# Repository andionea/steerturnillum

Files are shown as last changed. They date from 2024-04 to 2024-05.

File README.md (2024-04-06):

# SteerTurnIllum

## Getting started

To make it easy for you to get started with GitLab, here's a list of recommended next steps.

Already a pro? Just edit this README.md and make it your own. Want to make it easy? [Use the template at the bottom](#editing-this-readme)!

## Add your files

- [ ] [Create](https://docs.gitlab.com/ee/user/project/repository/web_editor.html#create-a-file) or [upload](https://docs.gitlab.com/ee/user/project/repository/web_editor.html#upload-a-file) files
- [ ] [Add files using the command line](https://docs.gitlab.com/ee/gitlab-basics/add-file.html#add-a-file-using-the-command-line) or push an existing Git repository with the following command:

```
cd existing_repo
git remote add origin https://gitlab.com/teodora.cristea/steerturnillum-ttc2.git
git branch -M main
git push -uf origin main
```

## Integrate with your tools

- [ ] [Set up project integrations](https://gitlab.com/teodora.cristea/steerturnillum-ttc2/-/settings/integrations)

## Collaborate with your team

- [ ] [Invite team members and collaborators](https://docs.gitlab.com/ee/user/project/members/)
- [ ] [Create a new merge request](https://docs.gitlab.com/ee/user/project/merge_requests/creating_merge_requests.html)
- [ ] [Automatically close issues from merge requests](https://docs.gitlab.com/ee/user/project/issues/managing_issues.html#closing-issues-automatically)
- [ ] [Enable merge request approvals](https://docs.gitlab.com/ee/user/project/merge_requests/approvals/)
- [ ] [Set auto-merge](https://docs.gitlab.com/ee/user/project/merge_requests/merge_when_pipeline_succeeds.html)

## Test and Deploy

Use the built-in continuous integration in GitLab.

- [ ] [Get started with GitLab CI/CD](https://docs.gitlab.com/ee/ci/quick_start/index.html)
- [ ] [Analyze your code for known vulnerabilities with Static Application Security Testing (SAST)](https://docs.gitlab.com/ee/user/application_security/sast/)
- [ ] [Deploy to Kubernetes, Amazon EC2, or Amazon ECS using Auto Deploy](https://docs.gitlab.com/ee/topics/autodevops/requirements.html)
- [ ] [Use pull-based deployments for improved Kubernetes management](https://docs.gitlab.com/ee/user/clusters/agent/)
- [ ] [Set up protected environments](https://docs.gitlab.com/ee/ci/environments/protected_environments.html)

***

# Editing this README

When you're ready to make this README your own, just edit this file and use the handy template below (or feel free to structure it however you want - this is just a starting point!). Thanks to [makeareadme.com](https://www.makeareadme.com/) for this template.

## Suggestions for a good README

Every project is different, so consider which of these sections apply to yours. The sections used in the template are suggestions for most open source projects. Also keep in mind that while a README can be too long and detailed, too long is better than too short. If you think your README is too long, consider utilizing another form of documentation rather than cutting out information.

## Name
Choose a self-explaining name for your project.

## Description
Let people know what your project can do specifically. Provide context and add a link to any reference visitors might be unfamiliar with. A list of Features or a Background subsection can also be added here. If there are alternatives to your project, this is a good place to list differentiating factors.

## Badges
On some READMEs, you may see small images that convey metadata, such as whether or not all the tests are passing for the project. You can use Shields to add some to your README. Many services also have instructions for adding a badge.

## Visuals
Depending on what you are making, it can be a good idea to include screenshots or even a video (you'll frequently see GIFs rather than actual videos). Tools like ttygif can help, but check out Asciinema for a more sophisticated method.

## Installation
Within a particular ecosystem, there may be a common way of installing things, such as using Yarn, NuGet, or Homebrew. However, consider the possibility that whoever is reading your README is a novice and would like more guidance. Listing specific steps helps remove ambiguity and gets people to using your project as quickly as possible. If it only runs in a specific context like a particular programming language version or operating system or has dependencies that have to be installed manually, also add a Requirements subsection.

## Usage
Use examples liberally, and show the expected output if you can. It's helpful to have inline the smallest example of usage that you can demonstrate, while providing links to more sophisticated examples if they are too long to reasonably include in the README.

## Support
Tell people where they can go to for help. It can be any combination of an issue tracker, a chat room, an email address, etc.

## Roadmap
If you have ideas for releases in the future, it is a good idea to list them in the README.

## Contributing
State if you are open to contributions and what your requirements are for accepting them.

For people who want to make changes to your project, it's helpful to have some documentation on how to get started. Perhaps there is a script that they should run or some environment variables that they need to set. Make these steps explicit. These instructions could also be useful to your future self.

You can also document commands to lint the code or run tests. These steps help to ensure high code quality and reduce the likelihood that the changes inadvertently break something. Having instructions for running tests is especially helpful if it requires external setup, such as starting a Selenium server for testing in a browser.

## Authors and acknowledgment
Show your appreciation to those who have contributed to the project.

## License
For open source projects, say how it is licensed.

## Project status
If you have run out of energy or time for your project, put a note at the top of the README saying that development has slowed down or stopped completely. Someone may choose to fork your project or volunteer to step in as a maintainer or owner, allowing your project to keep going. You can also make an explicit request for maintainers.

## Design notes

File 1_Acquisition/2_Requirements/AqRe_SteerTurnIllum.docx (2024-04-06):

System Requirements

SteerTurnIllum

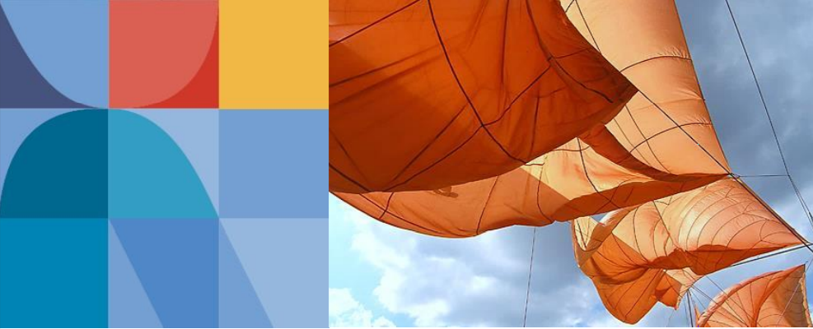
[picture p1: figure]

Author: | | Nicolae-Bogdan Bacrău
Version: | | 1.0

# Index

# 1 Glossary

This section contains a glossary of all the important terms and acronyms used inside the document.

Term / Acronym | Description
ECU | Electronic Control Unit
uC | Microcontroller
ADC | Analog Digital Converter
PWM | Pulse Width Modulation
EMC | Electromagnetic Compatibility

Table 1 - Glossary.

# 2 Introduction

## Purpose of the Document

The purpose of the document is to define the system requirements of the SteerTurnIllum embedded academy project.

## Overview

SteerTurnIllum is an abbreviation of Steering, Turning and Illumination, which represent the functional features of the emulated vehicle system:

1) Steering:
- Steering control of the vehicle through movements of a joystick, emulating the wheel, and indicated by servomotor angles.
- Horn control of the vehicle through pressing of a dedicated horn button and indicated by a buzzer activation.
2) Turning: control of turn signals (left, right and hazard signaling) through pressing three turn indication buttons and indicated on four turn indication LEDs through blinking; the position of the wheel can also stop the left or right turn indications.
3) Illumination: control of the vehicle board illumination through a potentiometer emulating the outer luminance and indicated on two illumination fading LEDs.

The system presents one extra feature, named Vehicle Management, which enables the user to switch between a normal state, in which the three functional states are active, and a configuration state in which several runtime configuration parameters can be set up which affect the behavior of the steering, turning and illumination features.

# 3 Methodology

## Steering

In the cars, the most conventional steering arrangement is to turn the front wheels using a hand operated steering wheel. Depending on the geometry of the wheels while steering, there are two possible steering control types:

- Parallel steering geometry: the wheels turn an identical angle when steering.
- Ackermann steering geometry: the inside wheel turns a greater angle than the outside wheel to follow the smaller radius that the inside wheel takes on a turn.

The two steering geometries are presented in Figure 1.

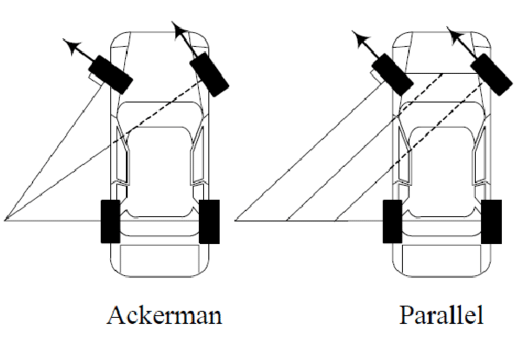
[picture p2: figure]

Figure 1 - Parallel vs Ackermann steering geometries.

While the parallel steering geometry is straightforward (the angles of the two wheels are identical), the Ackermann steering geometry defines a mathematical formula between the two angles, named: inner angle, δi (left angle when turning left, right angle when turning right) and the outer angle, δo (right angle when turning left, left angle when turning right). The Ackermann steering geometry is presented in Figure 2.

The Ackermann steering mathematical equation is:

ctg(δ_o )- ctg(δ_i )= w/l

Let w be half the size of l. In this case the equation of δo depending on δi is:

δ_o =arcctg(1/2+ctg(δ_i ))

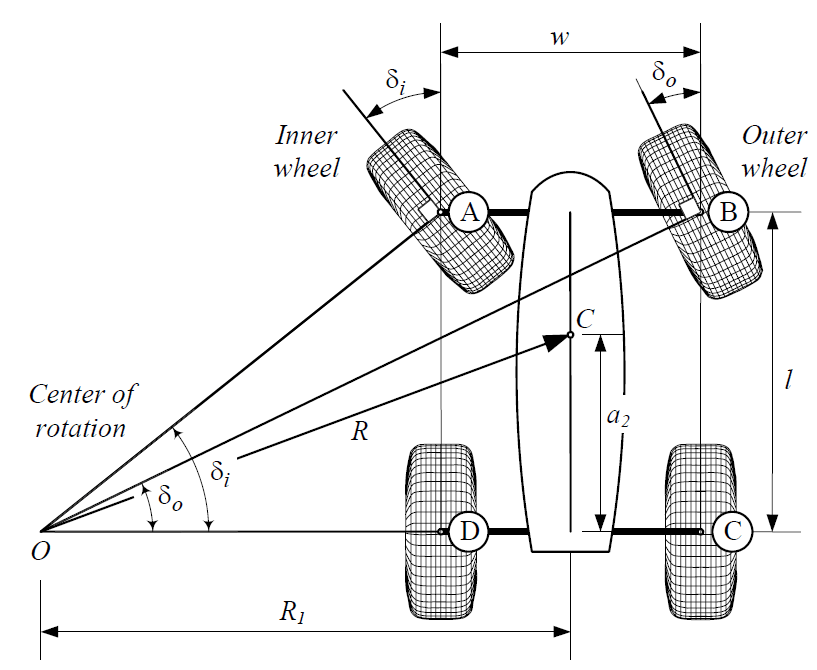
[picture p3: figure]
A-front-wheel-steering-vehicle-and-steer-angles-of-the-inner-and-outer-wheels

Figure 2 - Ackermann steering geometry.

A plot of outer wheel angles depending on inner wheel values is presented in Figure 3.

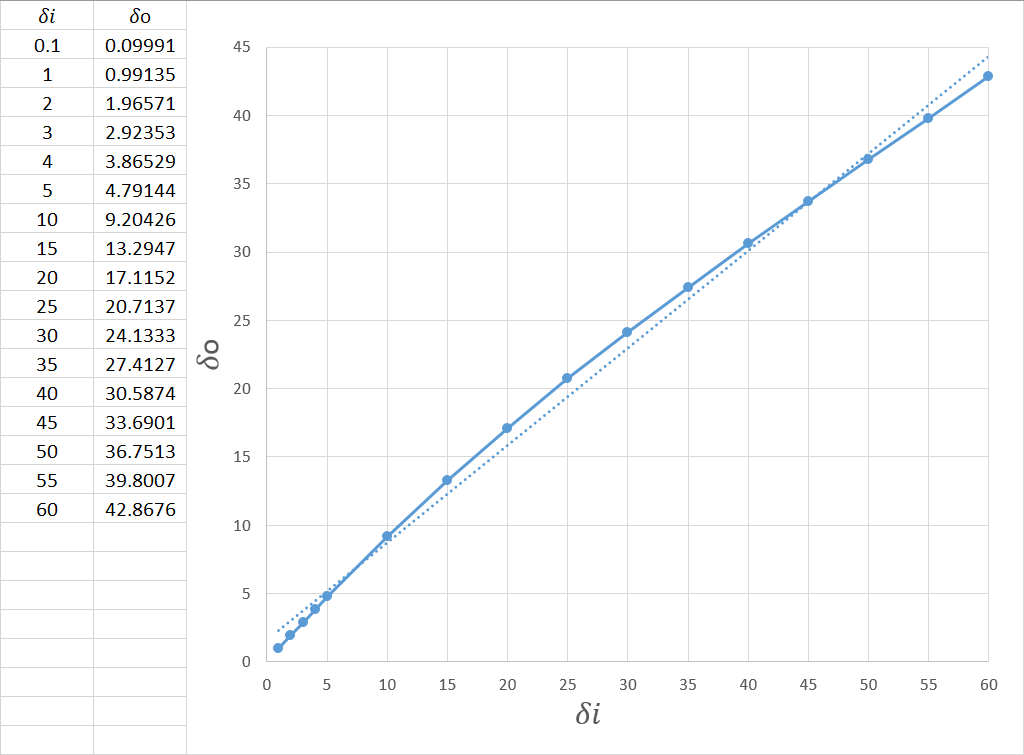
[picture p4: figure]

Figure 3 - Ackermann outer angles depending on inner angles.

The equation can be approximated through 4 linear equations, as shown in Figure 4.

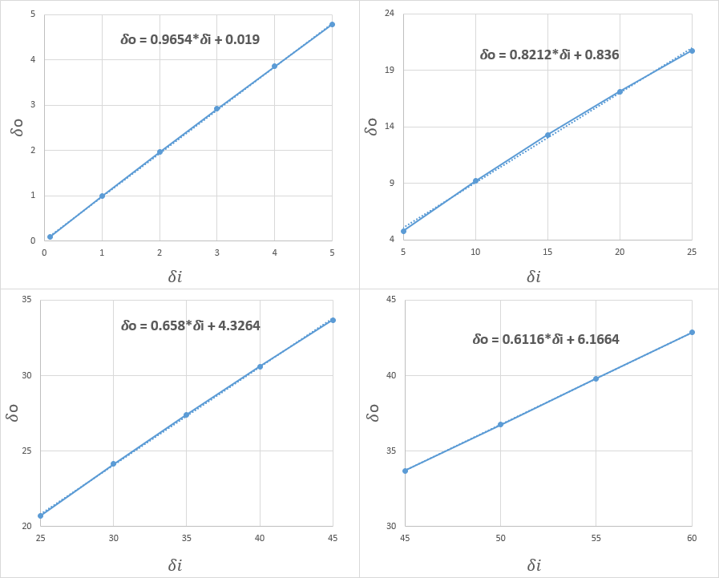
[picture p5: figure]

Figure 4 - Ackermann linear functions in the (0..60] degrees interval.

The 4 linear equations can be applied for inner angles in the (0..60] degrees interval. The Ackermann equation does not make sense for an inner angle of 0 degrees (ctg(0) is undefined). Therefore, when the inner angle is 0 the outer angle is also 0.

For more details see ./Resources/AqRe_Graphs.xlsx → Ackermann.

## Debouncing

In order to avoid frequent switching of the output values because of mechanical contact oscillation at button presses and releases, or because of EMC influence, the input values are debounced. This consists of considering a larger time interval than the contact maximum oscillation period or the EMC influence period in which the input values must be stable. By doing so, the probability of considering a wrong button state is greatly reduced.

Debouncing is defined by two values: the debounce window, representing the time period in which an input must be stable, and the debounce depth defining the number of times an input is sampled in the debounce window.

An example showing the result of a debounce with a depth of 4 on a button input signal that is affected by noise is illustrated in Figure 5.

Figure 5 - Debounce of a button input affected by noise.

A debounce depth of N means a debounce window equal to the sum of N-1 acquisition time window periodicities. In the given example, if the acquisition time would be 5 ms, then the debounce depth of 4 would mean a debounce window of (4-1)*5 = 15 ms.

Each mechanical button component has a maximum bouncing period of the contacts that is defined by the manufacturer / supplier of the component. It must be ensured that the chosen debounce time is larger than the defined bouncing period.

A measure for reducing the probability of erroneous button press events is to increase the debounce time of the buttons.

Observation: the debounce time greatly affects the response time, therefore it should be kept as low as possible (usually below 20 ms).

## Moving Average

A moving average is a simple Low Pass FIR (Finite Impulse Response) filter commonly used for regulating an array of sampled data. It takes a number of samples of input at a time, defining the Depth, and calculates the average of those samples, producing a single output value. As the length of the filter increases, the smoothness of the output increases, whereas the sharp modulations in the data are made increasingly blunt.

A moving average filter is described by the following formula:

F(t_x )=(∑_(k=x-D+1)^x S(t_x ))/D

- tx – a given point in time (timestamp);
- D – the filter depth;
- S(tx) – the sampled input signal;
- F(tx) – the filtered output.

An example of an input signal (S(tx)) and the output of a moving average filter (F(tx)) with a depth of 3 (D = 3) is presented in Figure 6.

Figure 6 - Moving average example.

For the given example, the filtered output in t5 is:

F(t_5 )=(S(t_3 )+S(t_4 )+S(t_5 ))/3=(2+8+5)/3=5

An example of filtering the output of a noisy ADC with a depth of 5 is presented in Figure 7.

Figure 7 - Moving average on a noisy ADC output.

The filtering operation adds a delay between the input values and the output values. For example, applying a moving average with D = 10 over the (0, 10, 10, 10, 10, 10, 10, 10, 10, 10, 10) input, results in the (0, 1, 2, 3, 4, 5, 6, 7, 8, 9, 10) output.

Observation: the depth of the moving average greatly affects the response time, therefore it should be kept as low as possible.

For more details see ./Resources/AqRe_Graphs.xlsx → Moving average.

## Fading

Sudden changes in the illumination levels are very easily observable by the human eye and can distract the driver’s attention. In order to diminish this effect, a slow transition between two illumination levels is needed. The transition, also called fading, consists of a series of intermediate illumination levels over a long period of time.

The illumination level is usually controlled via PWM signals applied on illumination LEDs. The actual illumination levels of the LEDs are not linearly correlated to the PWM duty cycle percentages, the changes in the illumination levels being more sensitive when the duty cycles are low. Therefore, in order to obtain a more linear transition of illumination levels, the used PWM duty cycles shall follow a non-linear equation. A good non-linear equation that satisfies a linear transition of illumination levels is:

FadingLevel(x)=x^4 , x∈[0, 1]

FadingLevel(x) takes values in the [0, 1] interval, defining PWM duty cycle percentages in the [0, 100]% interval. The graph of FadingLevel(x), using PWM duty cycle percentages, is presented in Figure 8.

Figure 8 - Fading levels graph.

Two examples of PWM duty cycle fading using the given equation are presented in Figure 9 and Figure 10.

Figure 9 - Fading PWM duty cycles from 0% to 30% in 150 ms with an update rate of 10 ms.

Figure 10 - Fading PWM duty cycles from 100% to 50% in 100 ms with an update rate of 10 ms.

For more details see ./Resources/AqRe_Graphs.xlsx → Fading.

# 4 System Requirements

## General

[SYRE_GEN_1] The system shall contain 3 x buttons for controlling the turn signals and 1 x button for controlling the horn activation, named and arranged in the following left to right order: BTN_LEFT, BTN_RIGHT, BTN_HAZARD, BTN_HORN.
[SYRE_GEN_2] The system shall contain 1 x joystick for controlling the steering angle, named JOY_STEER.
[SYRE_GEN_3] The JOY_STEER joystick shall be positioned such that left-right movements shall influence the steering control, left-most position meaning the 0% position and the right-most position meaning the 100% position. Top-bottom movements shall have no effect on the steering control. By default, the stick shall sit in the 50% position.
[SYRE_GEN_4] The system shall contain 1 x potentiometer for controlling the luminance, named POT_LUMINANCE.
[SYRE_GEN_5] The system shall contain 1 x buzzer for indicating the activation of the horn: BUZZ_HORN.
[SYRE_GEN_6] The system shall contain 4 x LEDs for indicating the turn signals, arranged in a square shape and named in the following clockwise order, starting from top-left: LED_TURN_FRONT_LEFT, LED_TURN_FRONT_RIGHT, LED_TURN_BACK_RIGHT, LED_TURN_BACK_LEFT.
[SYRE_GEN_7] The system shall contain 2 x red LEDs for indicating the board illumination, named and arranged in the following left to right order: LED_ILLUM_NIGHT, LED_ILLUM_DAY.
[SYRE_GEN_8] LED_ILLUM_NIGHT and LED_ILLUM_DAY shall be controlled via PWM channels with a frequency of 1600 Hz +- 10% and a duty cycle resolution of 0.01%.
[SYRE_GEN_9] The system shall contain 1 x dual 7 segments display for indicating the configuration states, named DISP7SEG.
[SYRE_GEN_10] The system shall contain 2 x servomotors for indicating the steering of the wheels, named and arranged in the following left to right order: SERVO_TURN_LEFT, SERVO_TURN_RIGHT.
[SYRE_GEN_11] All buttons shall be debounced in a 10 ms debounce window with a minimum depth of 3 (for more details see Chapter 3.2).
[SYRE_GEN_12] All analog channels shall be filtered using a moving average with a depth size of 5 over a 10 ms period (for more details see Chapter 3.3).

## Vehicle Management

[SYSRE_VEHM_1] The system shall implement the state machine illustrated in Figure 11.

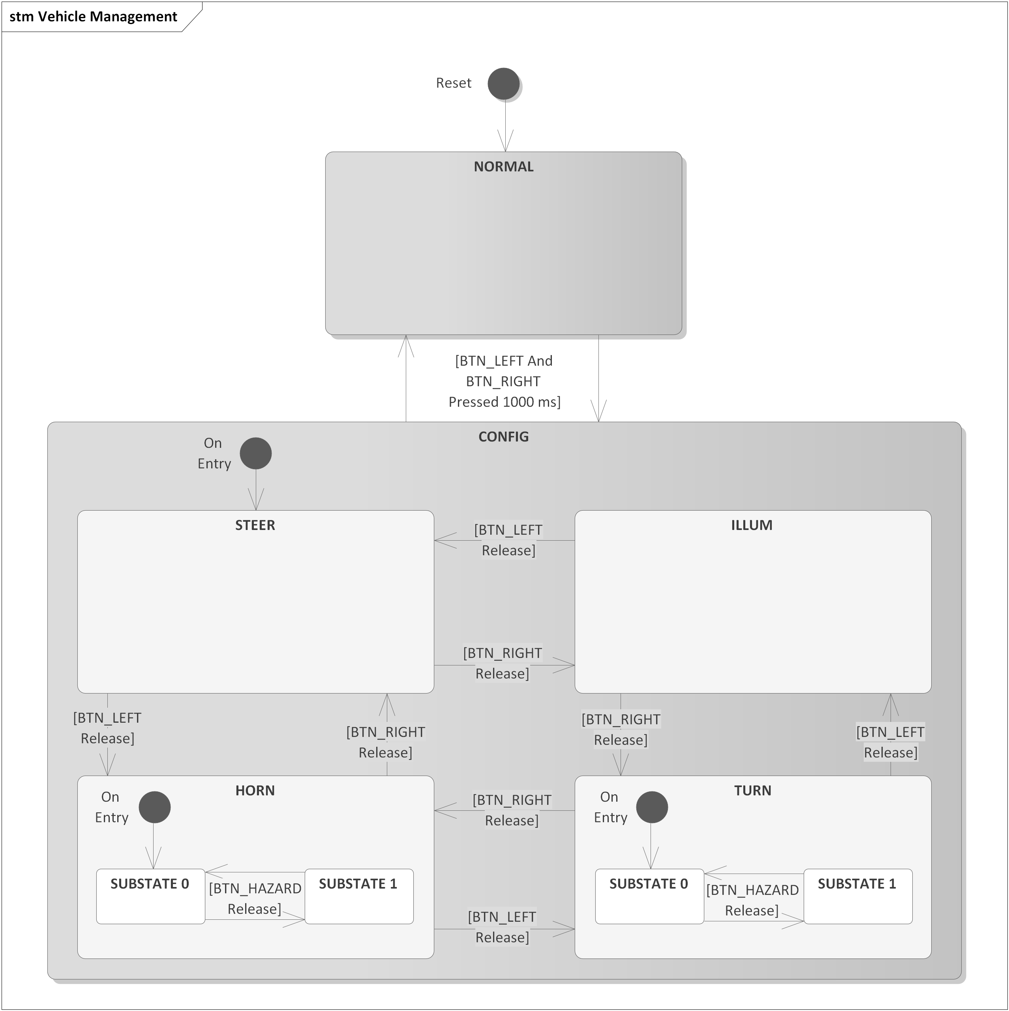
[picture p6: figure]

Figure 11 - Vehicle states and substates.

[SYSRE_VEHM_2] The default vehicle state after a reset shall be NORMAL.
[SYSRE_VEHM_3] The system shall set and react to the following runtime configuration parameters:
- SteerConfig: specifies the wheel steering outer angle calculation method – STEER_CONFIG_PARALLEL (0) or STEER_CONFIG_ACKERMANN (1).
- IllumConfig: specifies the period of the illumination fading – [300, 1000] ms – with a resolution of 10 ms.
- HornConfig:
  - Mode: specifies the horn activation mode – HORN_MODE_CONTINUOUS (0) or HORN_MODE_BEEPING (1).
  - Period: specifies the period of the horn signal while in the HORN_MODE_BEEPING mode – [50, 150] ms – with a resolution of 10 ms.
- TurnConfig:
  - Period: specifies the period of the indication signals – [200, 800] ms – with a resolution of 10 ms.
  - NrOfPeriods: specifies the number of periods to be used on a short turn indication – [2, 5] – with a resolution of 1.
[SYSRE_VEHM_4] The default values for the runtime configuration parameters after a reset shall be:
- SteerConfig = STEER_CONFIG_PARALLEL.
- IllumConfig = 500 ms.
- HornConfig.Mode = HORN_MODE_CONTINUOUS.
- HornConfig.Period = 100 ms.
- TurnConfig.Period = 500 ms.
- TurnConfig.NrOfPeriods = 3.
[SYSRE_VEHM_5] While in the CONFIG vehicle state, BUZZ_HORN shall be continuously inactive.
[SYSRE_VEHM_6] While in the CONFIG vehicle state SERVO_TURN_LEFT and SERVO_TURN_RIGHT shall be set in opposing directions at an inner angle of 45 degrees (135 degrees for SERVO_TURN_LEFT and 45 degrees for SERVO_TURN_RIGHT in trigonometric sense).
[SYSRE_VEHM_7] While in the CONFIG vehicle state JOY_STEER shall have no effect.
[SYSRE_VEHM_8] While in the CONFIG vehicle state, the correlation to be implemented between the states, substates, runtime configuration parameters to be saved, LEDs to be turned ON and values to be displayed on DISP7SEG is illustrated in Table 2.

State | Substate | Configuration Parameter | Active LEDs | DISP7SEG Values
STEER | - | SteerConfig | LED_TURN_FRONT_LEFT | [0, 1]
ILLUM | - | IllumConfig | LED_TURN_FRONT_RIGHT | [30, 100], 100 displayed as “1 ”
HORN | SUBSTATE 0 | HornConfig. Mode | LED_TURN_BACK_RIGHT, LED_ILLUM_NIGHT (10%) | [0, 1]
HORN | SUBSTATE 1 | HornConfig. Period | LED_TURN_BACK_RIGHT, LED_ILLUM_DAY (10%) | [5, 15]
TURN | SUBSTATE 0 | TurnConfig. Period | LED_TURN_BACK_LEFT, LED_ILLUM_NIGHT (10%) | [20, 80]
TURN | SUBSTATE 1 | TurnConfig. NrOfPeriods | LED_TURN_BACK_LEFT, LED_ILLUM_DAY (10%) | [2, 5]

Table 2 - Correlation between states, substates, configuration parameters, active LEDs and DISP7SEG values.

[SYSRE_VEHM_9] While in the CONFIG vehicle state and when BTN_HORN is not pressed, the user shall select the value to be set for the current runtime configuration parameter, indicated on DISP7SEG, through POT_LUMINANCE. DISP7SEG dot symbols shall be OFF.
[SYSRE_VEHM_10] While in the CONFIG vehicle state and when BTN_HORN is pressed, the selected value shall be frozen and saved into the current runtime configuration parameter (additional changed via POT_LUMINANCE shall have no effect on the displayed or saved value). DISP7SEG dot symbols shall be ON.

## Steering

[SYRE_STEER_1] The Steering feature shall be active only while in the NORMAL vehicle state.
[SYRE_STEER_2] When entering the NORMAL state, the servomotors shall point forwards and the buzzer shall be muted.
[SYRE_STEER_3] JOY_STEER position shall control the inner angle as follows:
- Left turn: (50 ... 0] % – (0 ... 60] degrees.
- Right turn: (50 ... 100] % – (0 ... 60] degrees.
[SYRE_STEER_4] When SteerConfig = STEER_CONFIG_PARALLEL, the outer angle shall be equal to the inner angle.
[SYRE_STEER_5] When SteerConfig = STEER_CONFIG_ACKERMANN, the outer angle shall be calculated based on the inner angle through the following equations (for more details see Chapter 3.1):
- δo = δi, when δi = 0;
- δo = 0.9654*δi + 0.019, when δi ∈ (0, 5];
- δo = 0.8212* δi + 0.836, when δi ∈ (5, 25];
- δo = 0.658*δi + 4.3264, when δi ∈ (25, 45];
- δo = 0.6116*δi + 6.1664, when δi ∈ (45, 60];
[SYRE_STEER_6] When BTN_HORN is pressed, the buzzer shall be activated as follows:
- When HornConfig.Mode = HORN_MODE_CONTINUOUS, the buzzer shall be continuously active.
- When HornConfig.Mode = HORN_MODE_BEEPING, the buzzer shall be controlled as illustrated in Figure 12.

Figure 12 - Horn beeping control signal.

[SYRE_STEER_7] When BTN_HORN is not pressed, the buzzer shall be continuously inactive.

## Turning

[SYRE_TURN_1] The Turning feature shall be active only while in the NORMAL vehicle state.
[SYRE_TURN_2] The Turning feature shall implement the state machine from Figure 13.

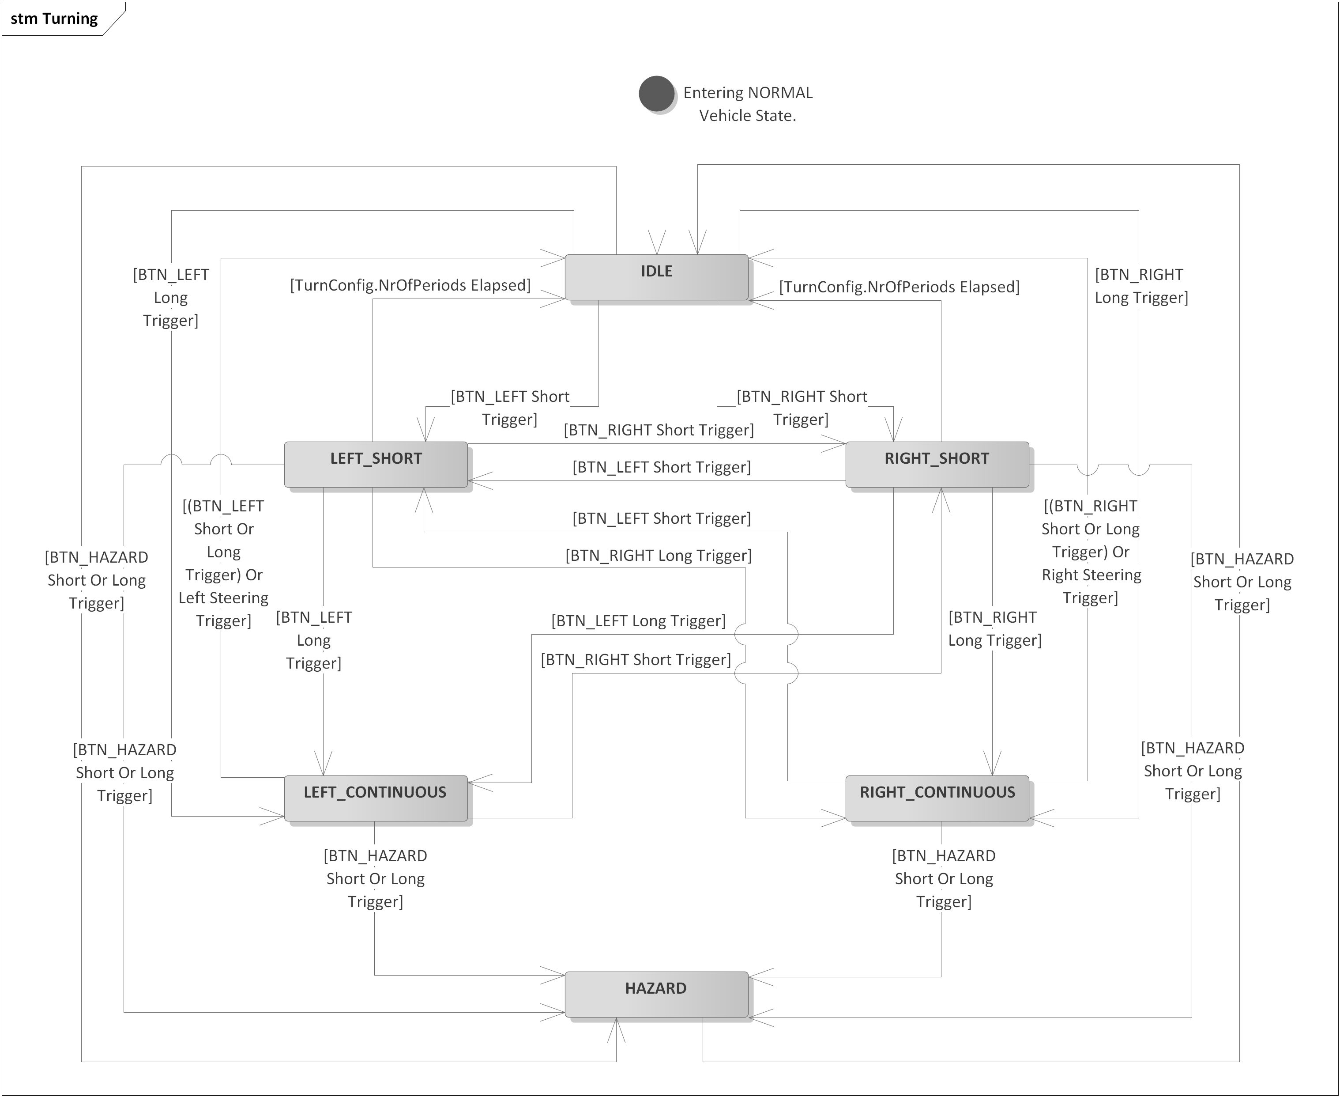
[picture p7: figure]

Figure 13 - Turning state machine.

[SYRE_TURN_3] While in the LEFT_SHORT, RIGHT_SHORT, LEFT_CONTINUOUS, RIGHT_CONTINUOUS, HAZARD states, the blinking LEDs shall be controlled as illustrated in Figure 14.

Figure 14 - LED blinking control signal.

[SYRE_TURN_4] While in the IDLE state, LED_TURN_FRONT_LEFT, LED_TURN_FRONT_RIGHT, LED_TURN_BACK_LEFT and LED_TURN_BACK_RIGHT, shall be turned OFF.
[SYRE_TURN_5] While in the LEFT_SHORT state, LED_TURN_FRONT_LEFT and LED_TURN_BACK_LEFT shall blink a number of times equal to TurnConfig.NrOfPeriods.
[SYRE_TURN_6] While in the RIGHT_SHORT state, LED_TURN_FRONT_RIGHT and LED_TURN_BACK_RIGHT shall blink a number of times equal to TurnConfig.NrOfPeriods.
[SYRE_TURN_7] While in the LEFT_CONTINUOUS state, LED_TURN_FRONT_LEFT and LED_TURN_BACK_LEFT shall blink continuously.
[SYRE_TURN_8] While in the RIGHT_CONTINUOUS state, LED_TURN_FRONT_RIGHT and LED_TURN_BACK_RIGHT shall blink continuously.
[SYRE_TURN_9] While in the HAZARD state, LED_TURN_FRONT_LEFT, LED_TURN_FRONT_RIGHT, LED_TURN_BACK_LEFT and LED_TURN_BACK_RIGHT shall blink continuously.
[SYRE_TURN_10] The short button trigger shall take place on the edge of a button being released after being continuously pressed for a period less than 500 ms.
[SYRE_TURN_11] The long button trigger shall take place when a button has been continuously pressed for a period of 500 ms (keeping the button pressed for more than 500 ms or releasing the button shall not create any other triggers).
[SYRE_TURN_12] The left steering trigger shall take place only in the LEFT_CONTINUOUS state when the steering wheel has reached a position >= 45% after previously reaching a position <= 35%.
[SYRE_TURN_13] The right steering trigger shall take place only in the RIGHT_CONTINUOUS state when the steering wheel has reached a position <= 55% after previously reaching a position >= 65%.

## Illumination

[SYRE_ILLUM_1] The Illumination feature shall be active only while in the NORMAL state.
[SYRE_ILLUM_2] When entering the NORMAL vehicle state, the illumination LEDs shall be OFF.
[SYRE_ILLUM_3] The illumination feature shall implement the state machine illustrated in Figure 15. The Illumination state machine depends on the following values and operations:
- CurrentLuminance: the current value of POT_LUMINANCE.
- AverageLuminance: the average value of CurrentLuminance.
- LastLuminance: the last processed AverageLuminance value for which a fading operation has been triggered.
- Duty(LuminanceValue): the target LED PWM duty cycle corresponding to the given LuminanceValue.
- Fading(LedChannel, StartDuty, TargetDuty, TimeMs): fading operation for the LedChannel LED, starting from the StartDuty PWM duty cycle, finishing when the TargetDuty PWM duty cycle value is reached, over a period of TimeMs miliseconds.

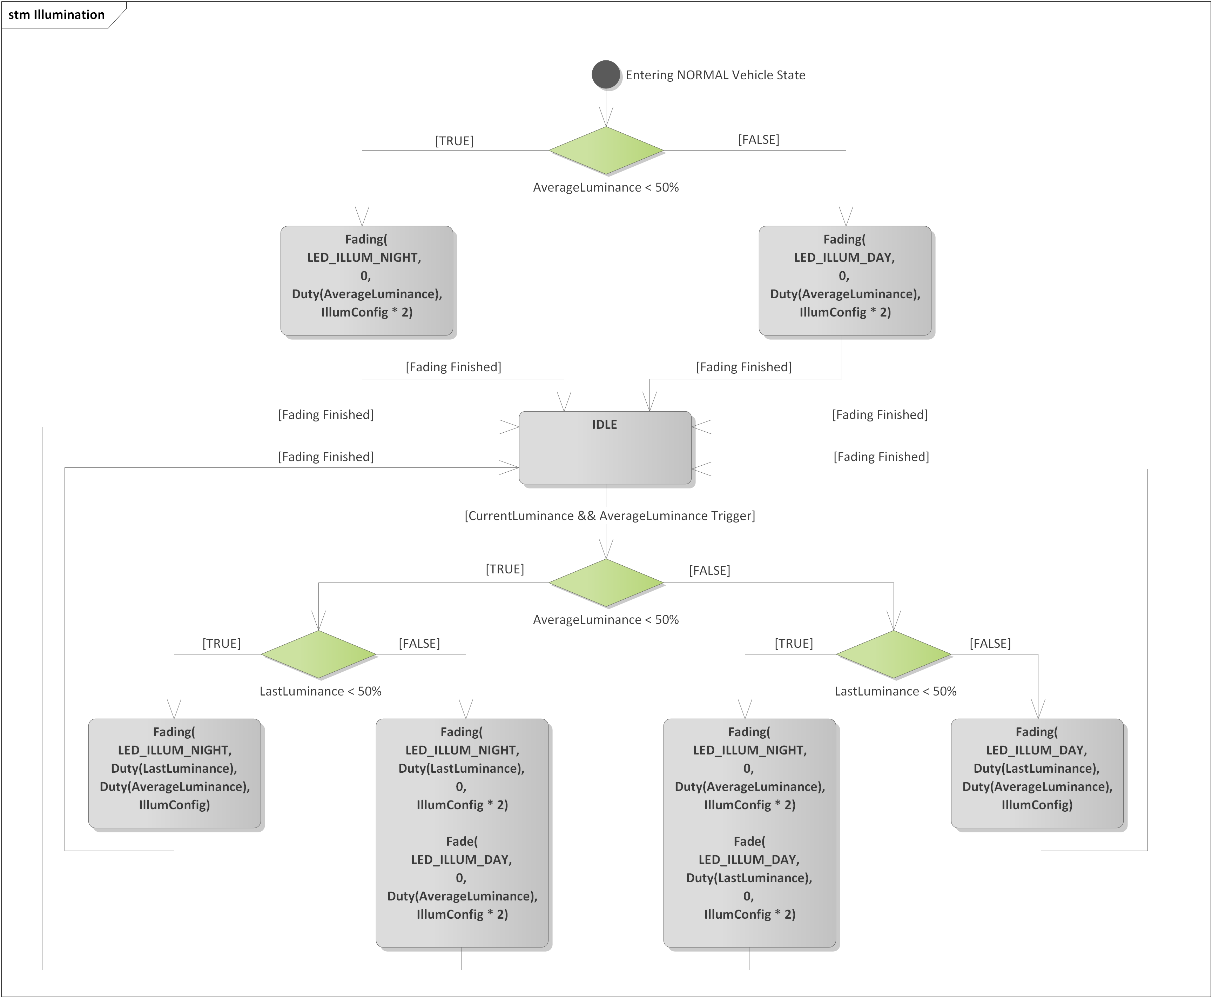
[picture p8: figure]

Figure 15 - Illumination state machine.

[SYRE_ILLUM_4] AverageLuminance shall be calculated with a moving average of size >= 25 over a period of 500 ms.
[SYRE_ILLUM_5] After entering the NORMAL vehicle state, the first decision point for AverageLuminance (< or >= 50%) shall be executed only after a full averaging of CurrentLuminance over a period of 500 ms has finished.
[SYRE_ILLUM_6] While in the IDLE state, the PWM duty cycles of both illumination LEDs shall remain constant.
[SYRE_ILLUM_7] Once a Fading() operation starts, no additional fading triggers shall take place until the ongoing operation finishes. AverageLuminance shall be continuously updated, even if a Fading() operation is ongoing.
[SYRE_ILLUM_8] The fading trigger from the IDLE state shall take place only when the following conditions are met. DELTA shall be 0.5%.

(

(AverageLuminance < (CurrentLuminance + DELTA) )

AND

(AverageLuminance>(CurrentLuminance - DELTA) )

)

AND

(

(AverageLuminance < (LastLuminance - DELTA))

OR

(AverageLuminance > (LastLuminance + DELTA))

)

[SYRE_ILLUM_9] Duty(LuminanceValue) shall be calculated with linear interpolation as follows:
- Night mode: LuminanceValue = [0, 50] -> Duty(LuminanceValue) = [0.5, 15]%;
- Day mode: LuminanceValue = [50, 100] -> Duty(LuminanceValue) = [20, 100]%.
[SYRE_ILLUM_10] The Fading() operation shall consist of a variation of PWM duty cycle levels following the following equation:

FadingLevel(x)=x^4 , x∈[0, 1]

FadingLevel(x) takes values in the [0, 1] interval, defining PWM duty cycle percentages in the [0, 100]% interval (for more details see Chapter 3.4).

[SYRE_ILLUM_11] The Fading() operation shall perform a duty cycle level update once every 10 ms.

# 5 Information about this Document

## 1.1 Copyright

All rights, including translation rights, are reserved. Under no circumstances shall any fragment of this document be reproduced without written authorization from NTT DATA Romania S.A, including copying, photographing or replicating through other methods.

Copyright (c) NTT DATA Romania S.A.

## 1.2 Version Index

Version | Date | Author | Chapter | Modification description
1.0 | 10.07.2021 | Nicolae-Bogdan Bacrău | All | Created.

Table 3 - Version Index.

Copyright © NTT DATA Romania S.A. Page 8 of 22

Information Type: Working Standard Information Owner: Nicolae-Bogdan Bacrău Company: NTT DATA Romania

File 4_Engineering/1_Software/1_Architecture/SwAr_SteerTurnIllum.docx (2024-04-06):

Software Architecture

SteerTurnIllum


Author: | | Nicolae-Bogdan Bacrău
Version: | | 1.0

# Index

# 1 Glossary

This section contains a glossary of all the important terms and acronyms used inside the document.

Term / Acronym | Description
AUTOSAR | AUTomotive Open System ARchitecture
VFB | Virtual Functional Bus
SWC | Software Component
RTE | Runtime Environment
BSW | Basic Software
OS | Operating System
S/R | Sender / Receiver
C/S | Client / Server
ECU | Electronic Control Unit
uC | Microcontroller
ADC | Analog Digital Converter
DIO | Digital Input / Output
PWM | Pulse Width Modulation

Table 1 - Glossary.

# 2 Introduction

## Purpose of the Document

The purpose of the document is to define the software architecture of the SteerTurnIllum embedded academy project.

## Overview

The software architecture of SteerTurnIllum is based on AUTOSAR and consists of the following:

- Building Blocks – enumerates all the software system’s modules and their abstraction level.
- Virtual Functional Bus – defines the communication between all the software system’s SWCs through ports and connectors.
- Features – defines the components diagram and the runtime sequence diagrams for each feature.

# 3 Building Blocks

[SWAR_1] The building blocks of the software system shall consist of the components illustrated in Figure 1.

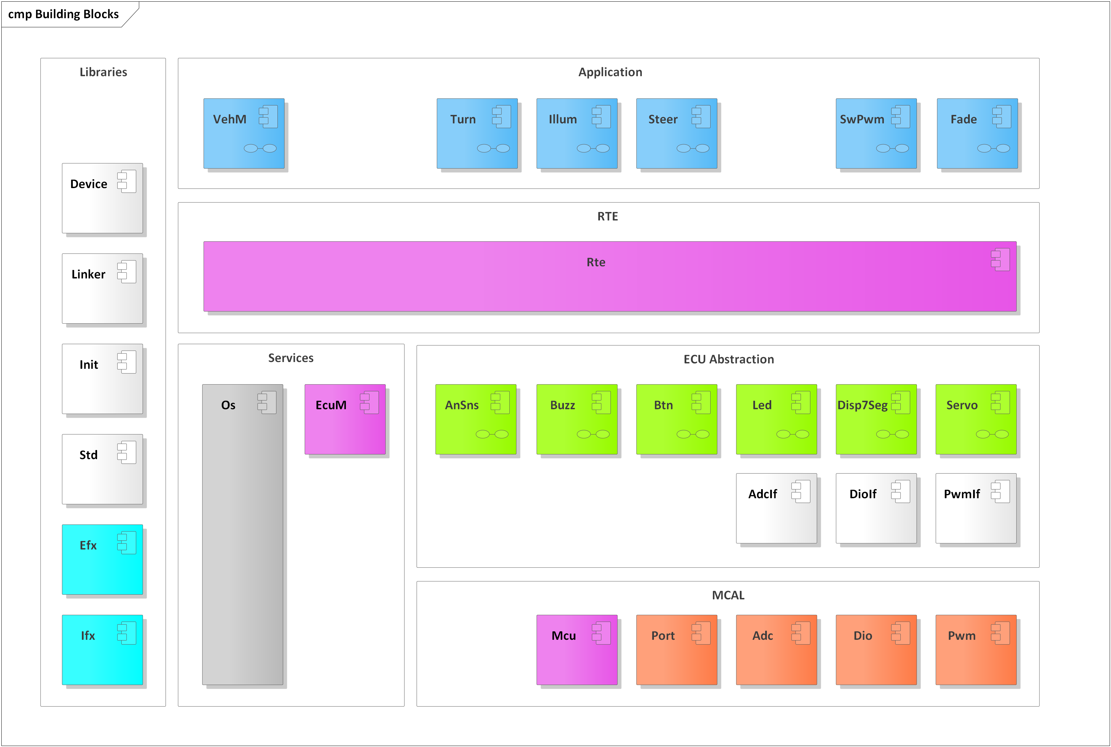
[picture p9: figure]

Figure 1 - Building Blocks Diagram.

The colors of the modules in the building blocks have the following significance:

- White: provided as full source code; no implementation required.
- Grey: provided as libraries and headers; no implementation required.
- Purple: full implementation provided as libraries; partial implementation provided as source code; requires partial implementation.
- Cyan, Red, Green and Blue: full implementation provided as libraries; requires full implementation.

Each of the Purple, Cyan, Red, Green and Blue modules are described in detail in a dedicated separate design requirements document.

The White and Grey modules are part of the framework and have the following purposes:

- Device:
  - Contains data types and masks for working with the uC registers.
- Linker:
  - Contains the description of linker script symbols that are needed for initializing RAM sections.
- Init (Initialization):
  - Contains data types and functions for writing lists of (8, 16 or 32 bit) variables to desired initialization values.
  - The functions are of two types: full, which fully write the variables to the given values, or masked, which use AND and OR masks for writing only parts of the variables.
- Std (Standard Definitions):
  - Contains the definition of the AUTOSAR data types and macros.
- AdcIf (ADC Interface):
  - Contains data type and interface definitions for accessing ADCs on the ECU level. In this implementation only uC internal ADC channels are used, so the data types and interfaces are defined as the ones from the ADC driver.
  - Redefines the ADC channels from names containing the uC port name and port channel ID to names referencing the peripherals from the hardware schematic.
- DioIf (DIO Interface):
  - Contains data type and interface definitions for accessing DIOs on the ECU level. In this implementation only uC internal DIO channels and ports are used, so the data types and interfaces are defined as the ones from the DIO driver.
  - Redefines the DIO channels and ports from names containing the uC port name and port channel ID to names referencing the peripherals from the hardware schematic.
- PwmIf (PWM Interface):
  - Contains data type and interface definitions for accessing PWMs on the ECU level. In this implementation only uC internal PWM channels are used, so the data types and interfaces are defined as the ones from the PWM driver.
  - Redefines the PWM channels from names containing the uC port name and port channel ID to names referencing the peripherals from the hardware schematic.
- Os (Operating System):
  - Makes use of a hardware timer for keeping track of the elapsed time and cyclically calls (with statically configured periodicities) OS tasks, implemented in the RTE.

# 4 Virtual Functional Bus

[SWAR_2] The Virtual Functional Bus of the software system, defining the interaction between all SWCs, shall consist of the ports and connectors illustrated in Figure 2.

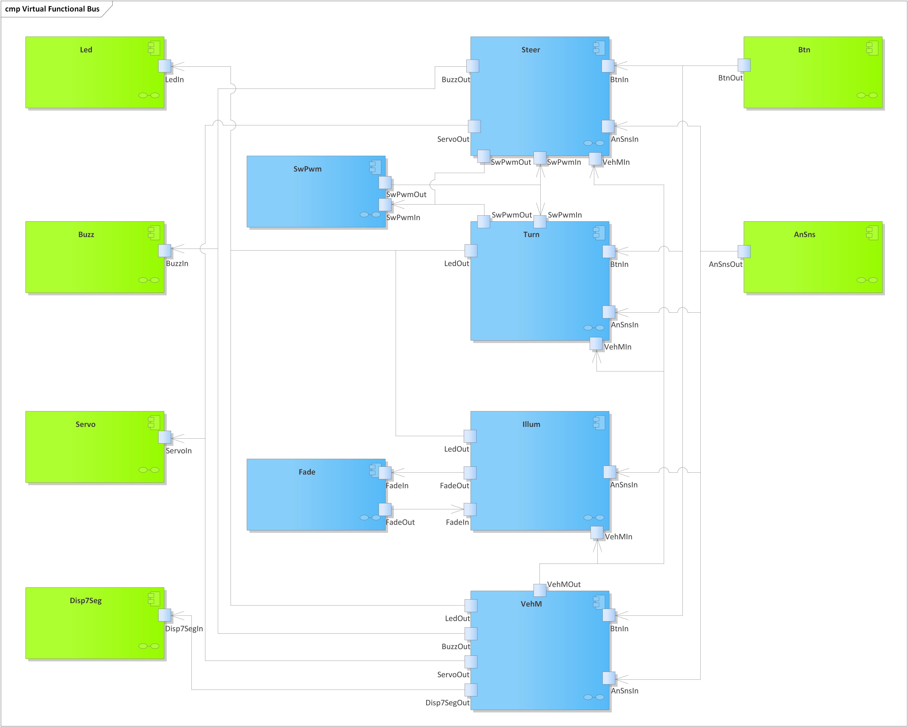
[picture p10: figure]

Figure 2 - Virtual Functional Bus diagram.

There are two types of SWCs:

- Application SWCs (Blue):
  - Located above the RTE, in the Application layer.
  - Only use RTE interfaces for interacting with the BSW and other SWCs.
  - No hardware dependencies.
- ECU Abstraction SWCs (Green):
  - Located below the RTE, in the ECU Abstraction layer.
  - Use RTE interfaces for interacting with BSW and the other SWCs.
  - Direct access to the ECU Abstraction interface modules for accessing the ADC, DIO and PWM resources on an ECU level.

The SWCs are software modules that implement a clearly defined behavior and can interact with each other only via the RTE, through clearly defined ports. In this architecture all the ports are S/R ports. No C/S ports are used.

The S/R ports are logical groups of interfaces for reading or writing data. The SWCs cannot call functions from other modules nor directly read / write global variables declared in other modules.

In order to assure the interaction between SWCs, the RTE declares global data buffers (global variables) and provides read and write interfaces for getting and setting their values. Each SWC has its own unique set of RTE read and write interfaces, accessible by including a dedicated header (Rte_<SWC_Name>.h).

Each SWC exports runnables. A runnable is a special type of function that can only be called inside an RTE task. There are two types of runnables:

- Initialization runnable – called only once, after reset, in the initialization task.
- Cyclic runnables (also called main functions) – called inside cyclic RTE tasks; which task depends on the timing constraints of the system requirements (it is up to the developer to choose).

# 5 Features

The software features in this chapter are correlated with the system features from the system requirements. Each software feature defines:

- Components diagram: defines the list of software components and the interaction between them through the interfaces that are relevant for the given feature.
- Runtime sequence diagram: presents the order of execution of all the runnables and the interactions with the RTE through S/R interfaces, defining the chronological data flow between the components.

For simplicity, some interfaces, although are part of the components, do not appear in some feature diagrams since they are not relevant for that feature.

The components and runtime sequence diagrams illustrate the actual S/R interfaces (C functions) that are used for communicating. The interfaces follow a naming convention:

- Rte_Read_<PortName>_<DataElementName> – for reading data elements.
- Rte_Write_<PortName>_<DataElementName> – for writing data elements.

The software features are executed in parallel.

## Vehicle Management

### Components

[SWAR_3] The Vehicle Management feature shall consist of the components, interfaces and dependencies illustrated in the components diagram from Figure 3.

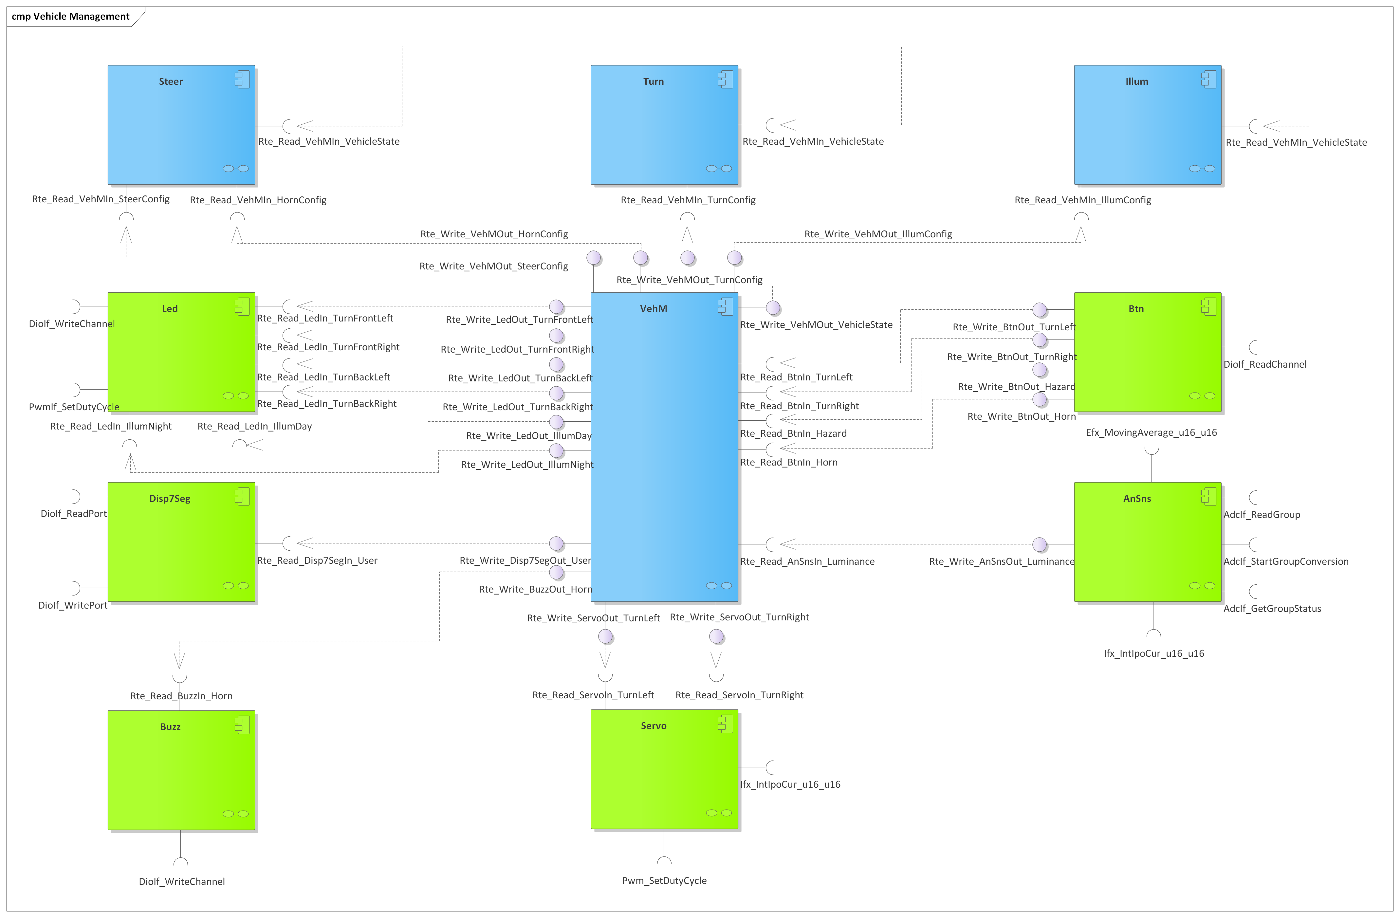
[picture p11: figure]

Figure 3 - Vehicle Management components diagram.

### Runtime

[SWAR_4] The Vehicle Management feature shall adhere to the execution order illustrated in the runtime sequence diagram from Figure 4.

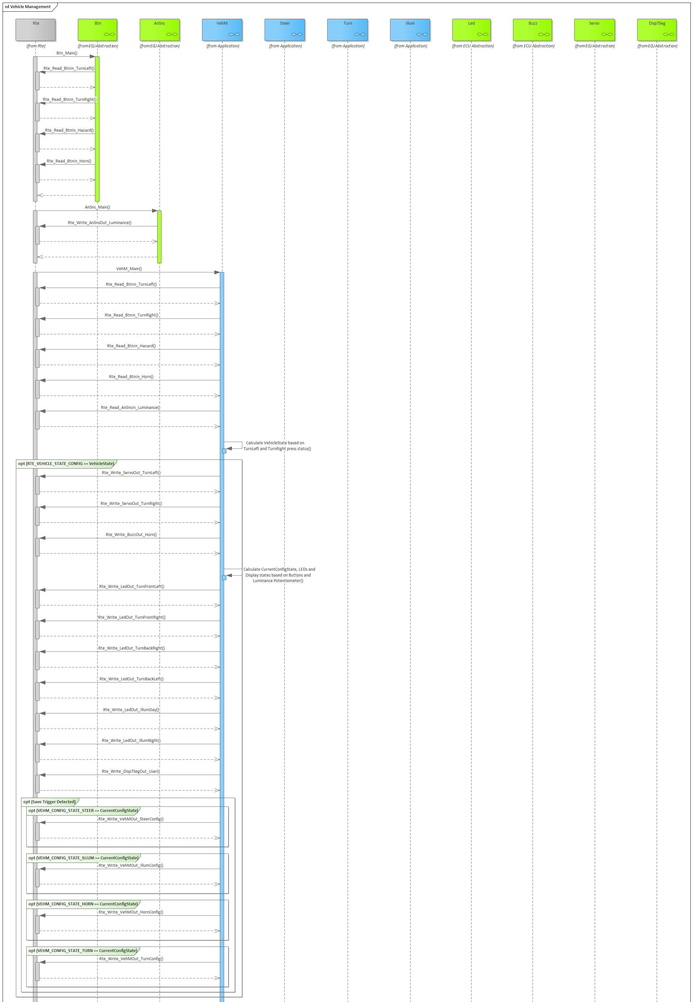
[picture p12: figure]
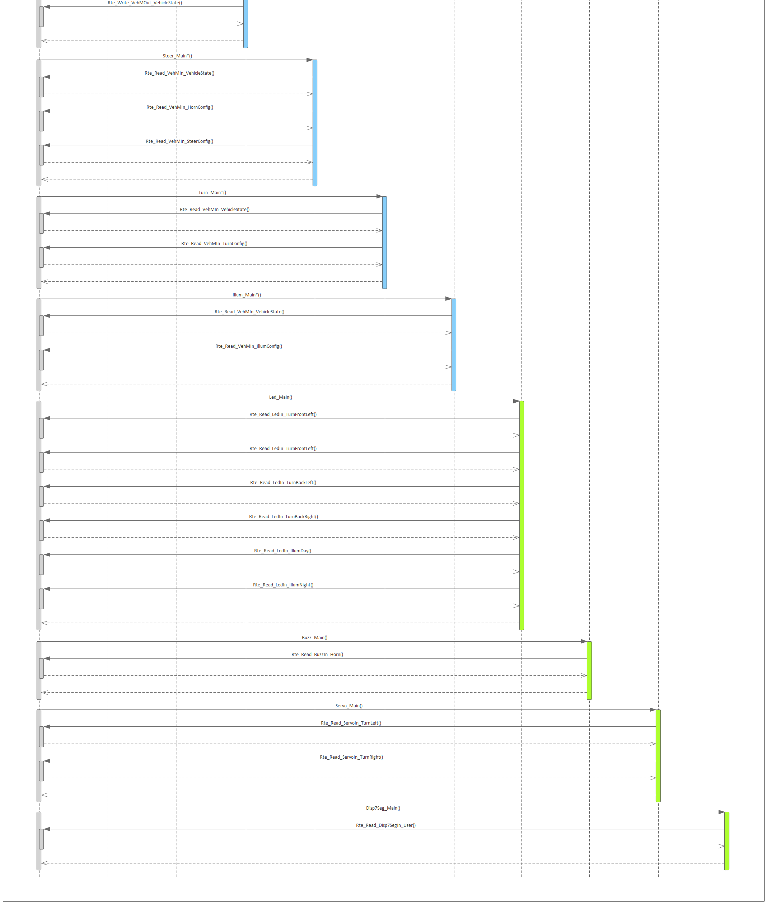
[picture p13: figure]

Figure 4 - Vehicle Management runtime sequence diagram.

## Steering

### Components

[SWAR_5] The Steering feature shall consist of the components, interfaces and dependencies illustrated in the components diagram from Figure 5.

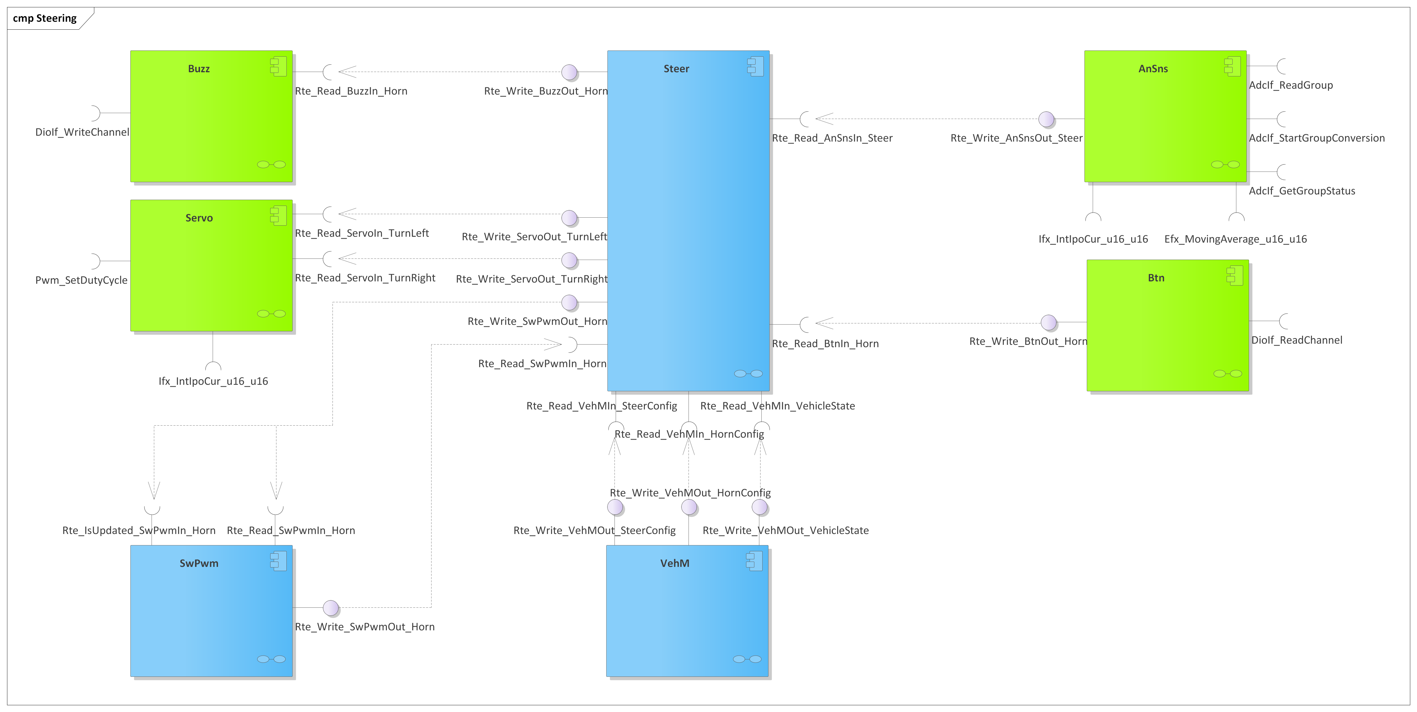
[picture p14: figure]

Figure 5 - Steering components diagram.

### Runtime

[SWAR_6] The Steering feature shall adhere to the execution order illustrated in the runtime sequence diagram from Figure 6.

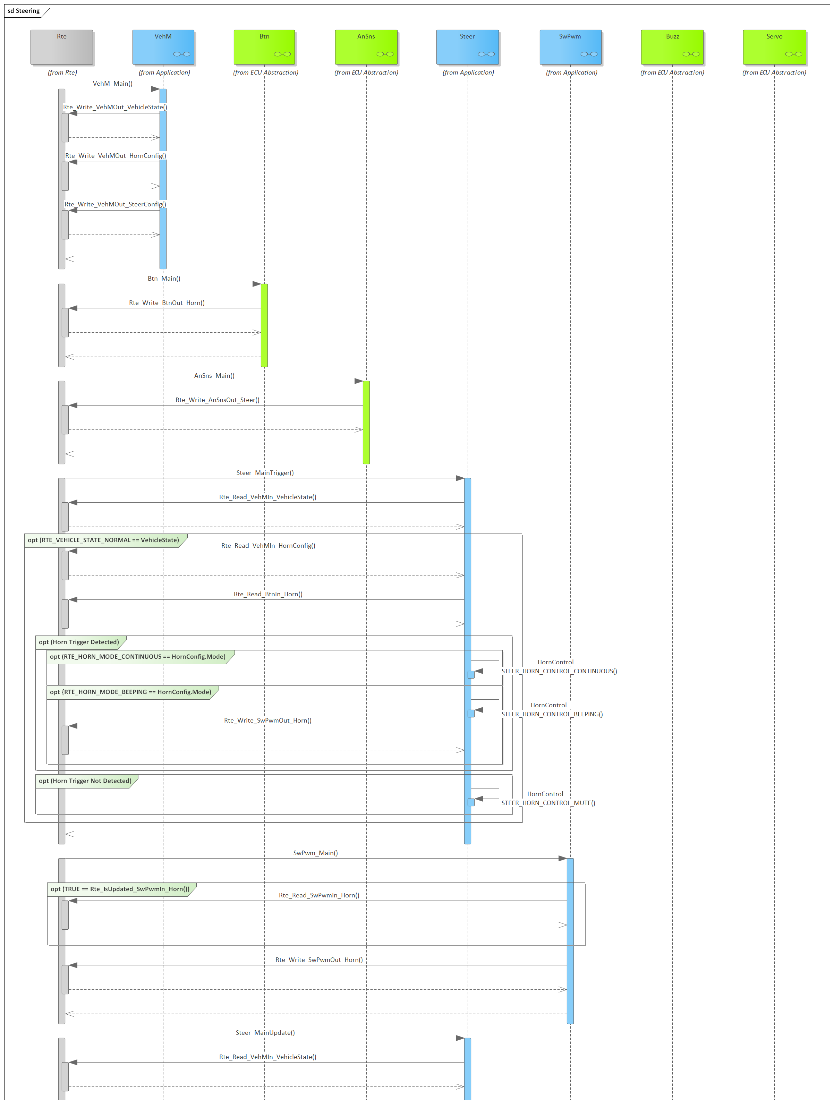
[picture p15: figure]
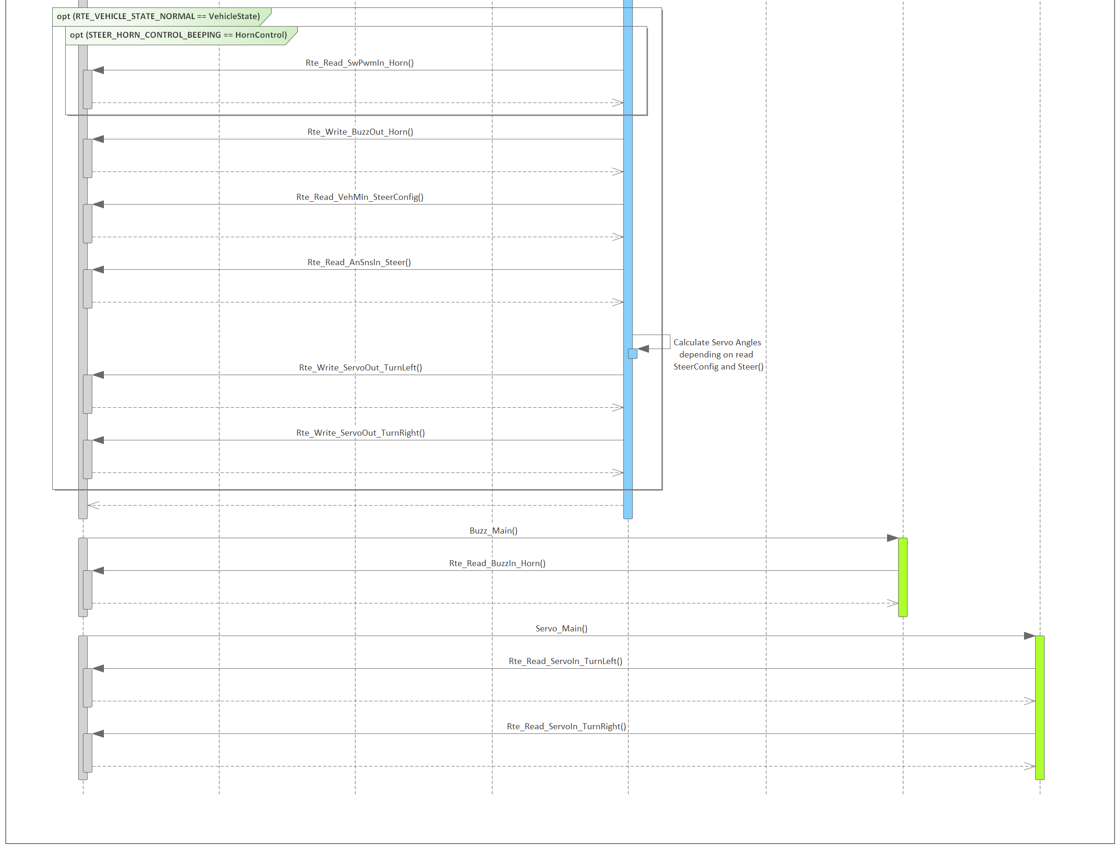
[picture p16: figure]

Figure 6 - Steering runtime sequence diagram.

## Turning

### Components

[SWAR_7] The Turning feature shall consist of the components, interfaces and dependencies illustrated in the components diagram from Figure 7.

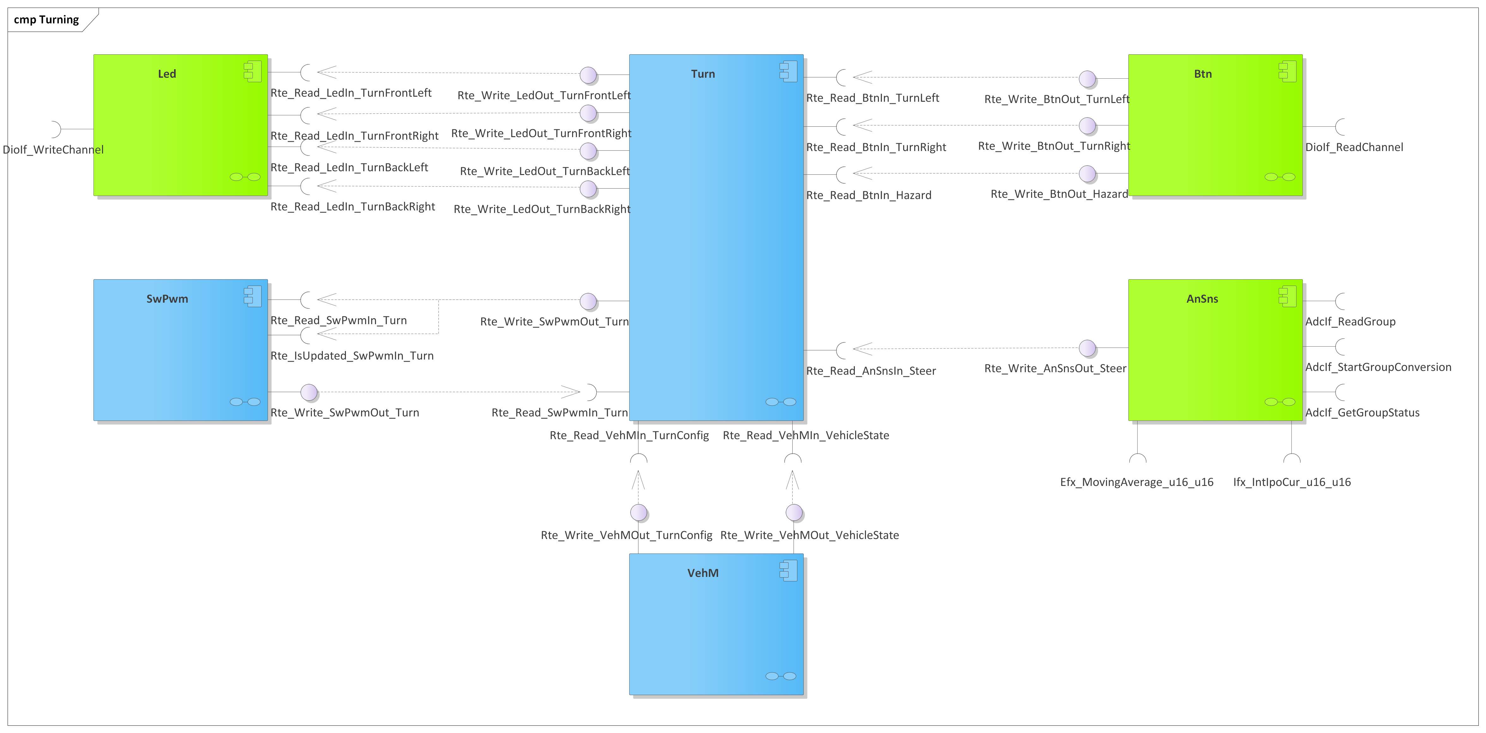
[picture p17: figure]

Figure 7 - Turning components diagram.

### Runtime

[SWAR_8] The Turning feature shall adhere to the execution order illustrated in the runtime sequence diagram from Figure 8.

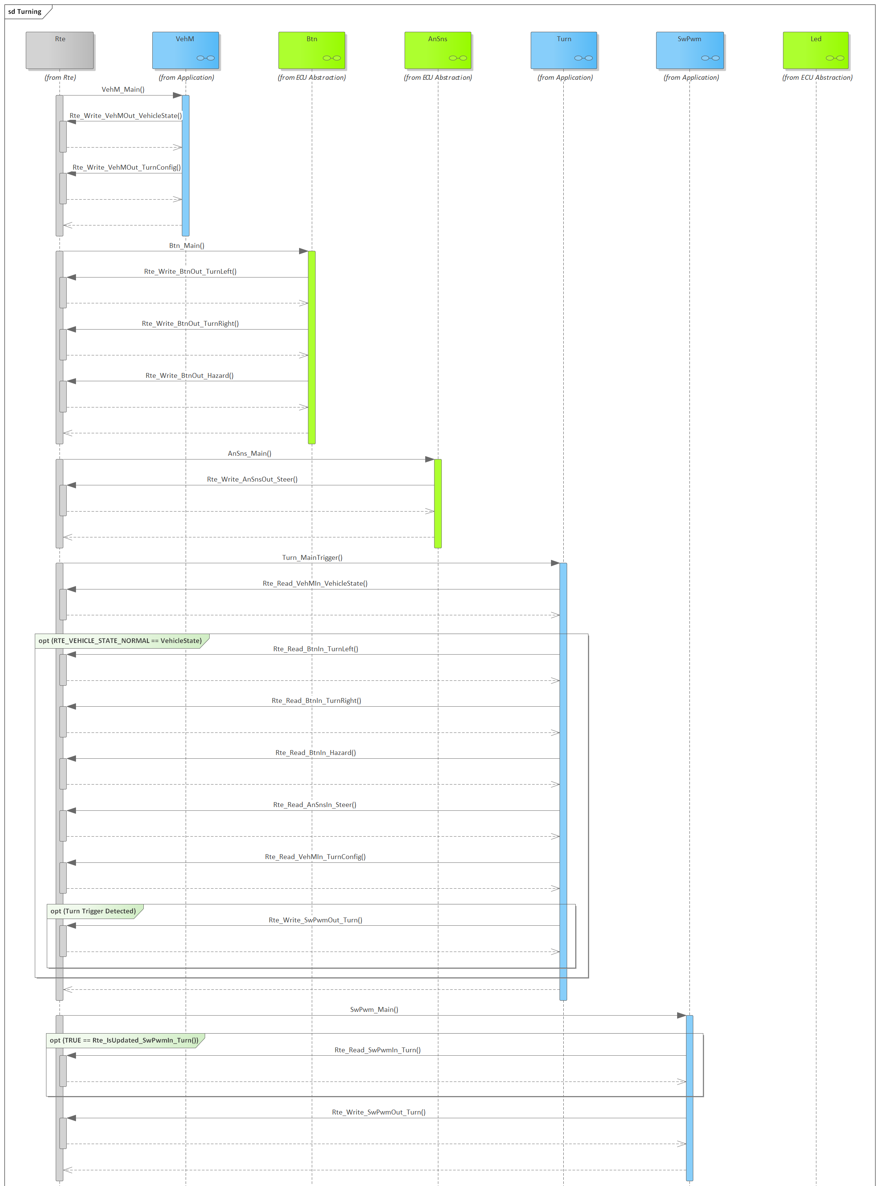
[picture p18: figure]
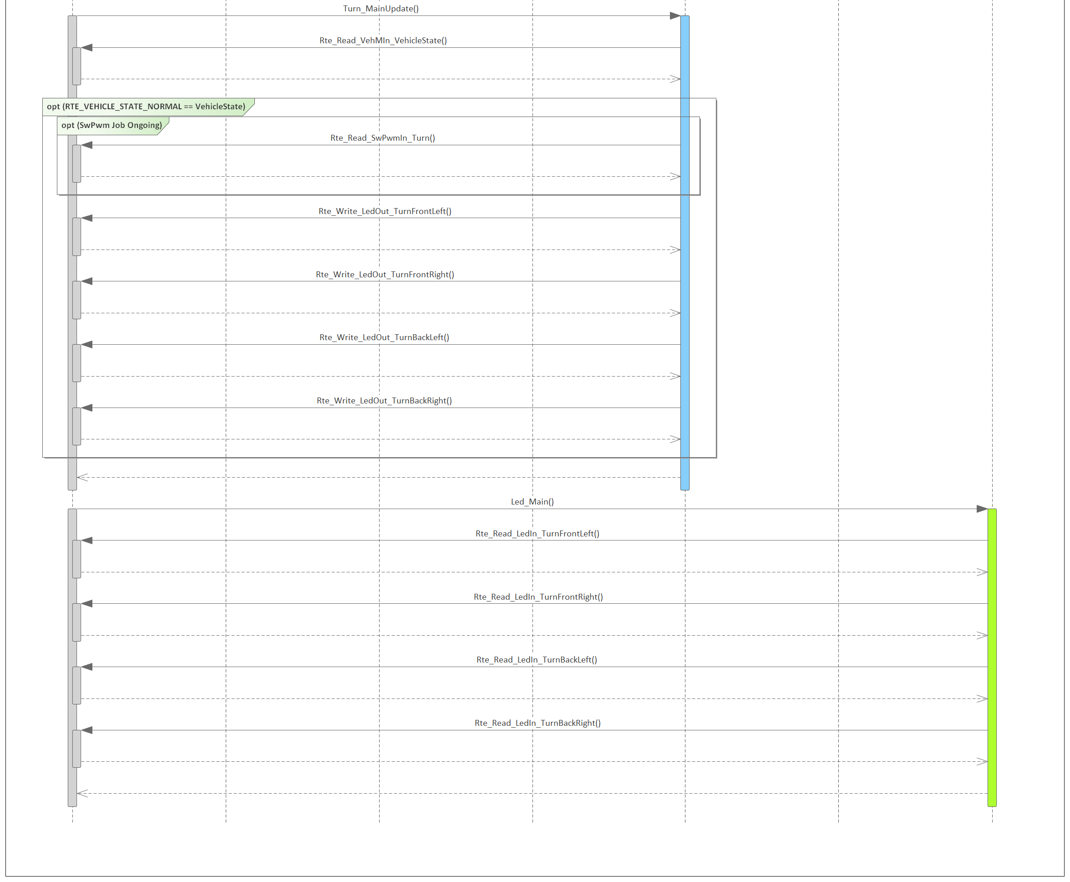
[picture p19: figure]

Figure 8 - Turning runtime sequence diagram.

## Illumination

### Components

[SWAR_9] The Illumination feature shall consist of the components, interfaces and dependencies illustrated in the components diagram from Figure 9.

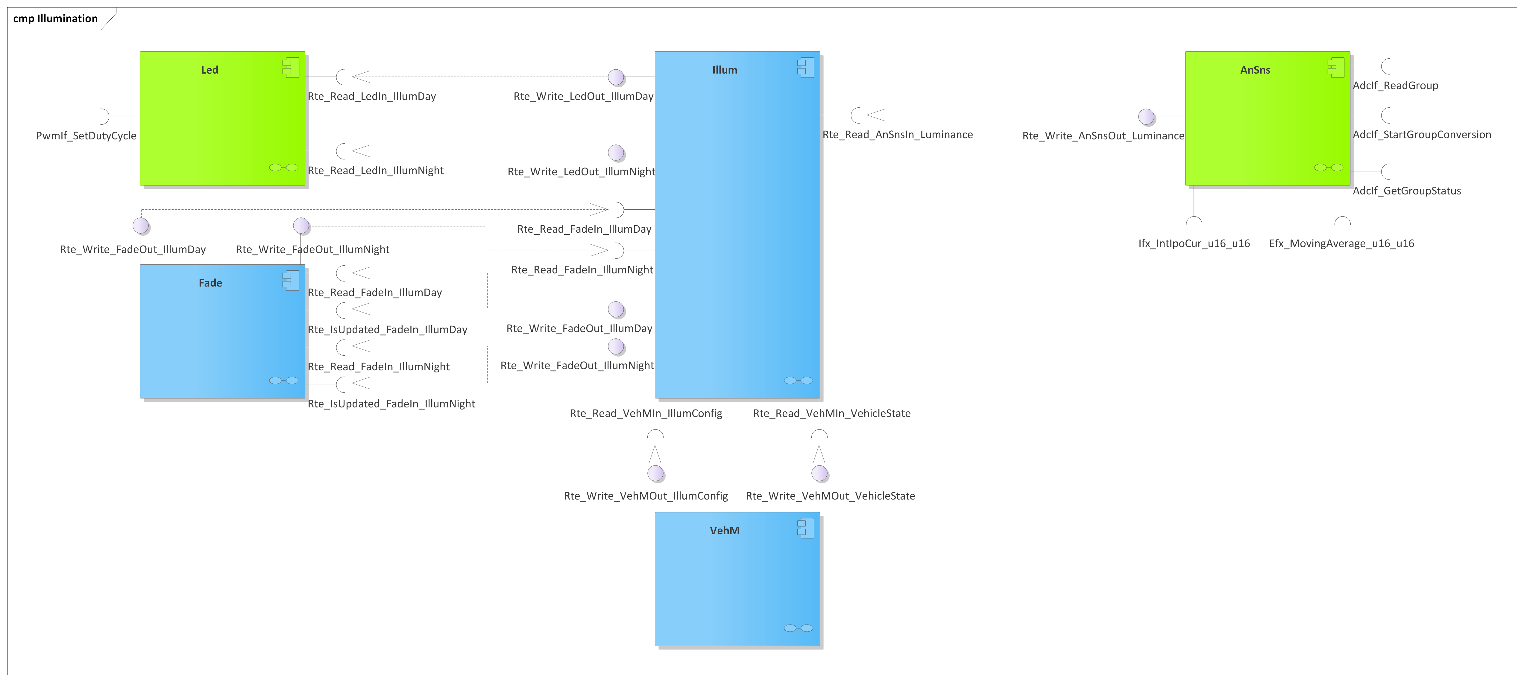
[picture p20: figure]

Figure 9 - Illumination components diagram.

### Runtime

[SWAR_10] The Illumination feature shall adhere to the execution order illustrated in the runtime sequence diagram from Figure 10.

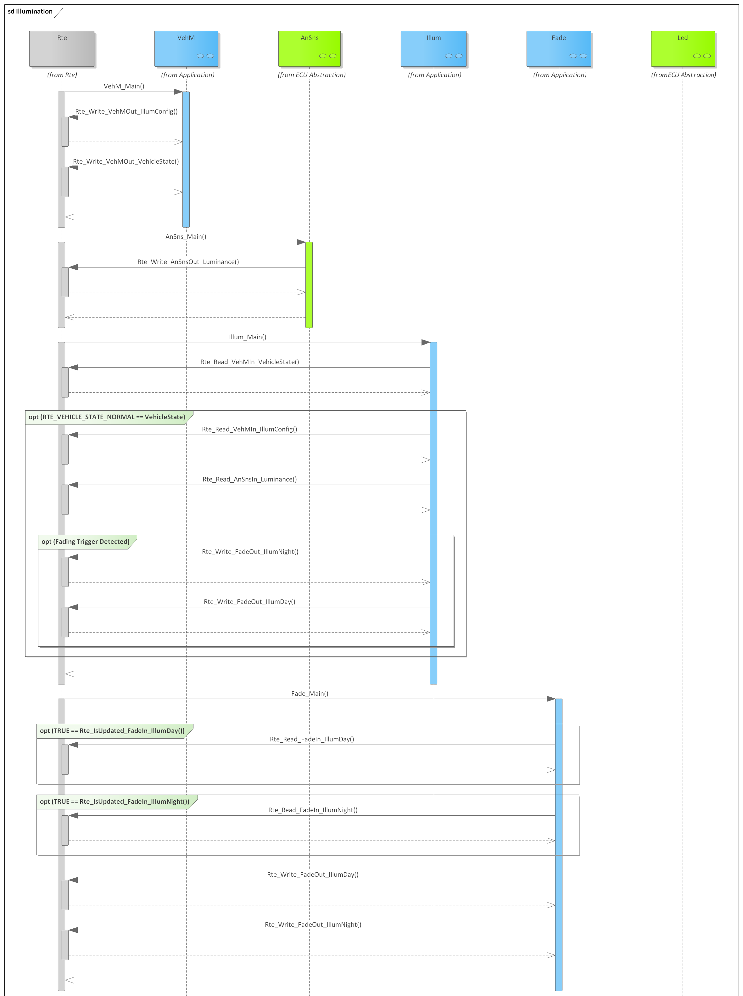
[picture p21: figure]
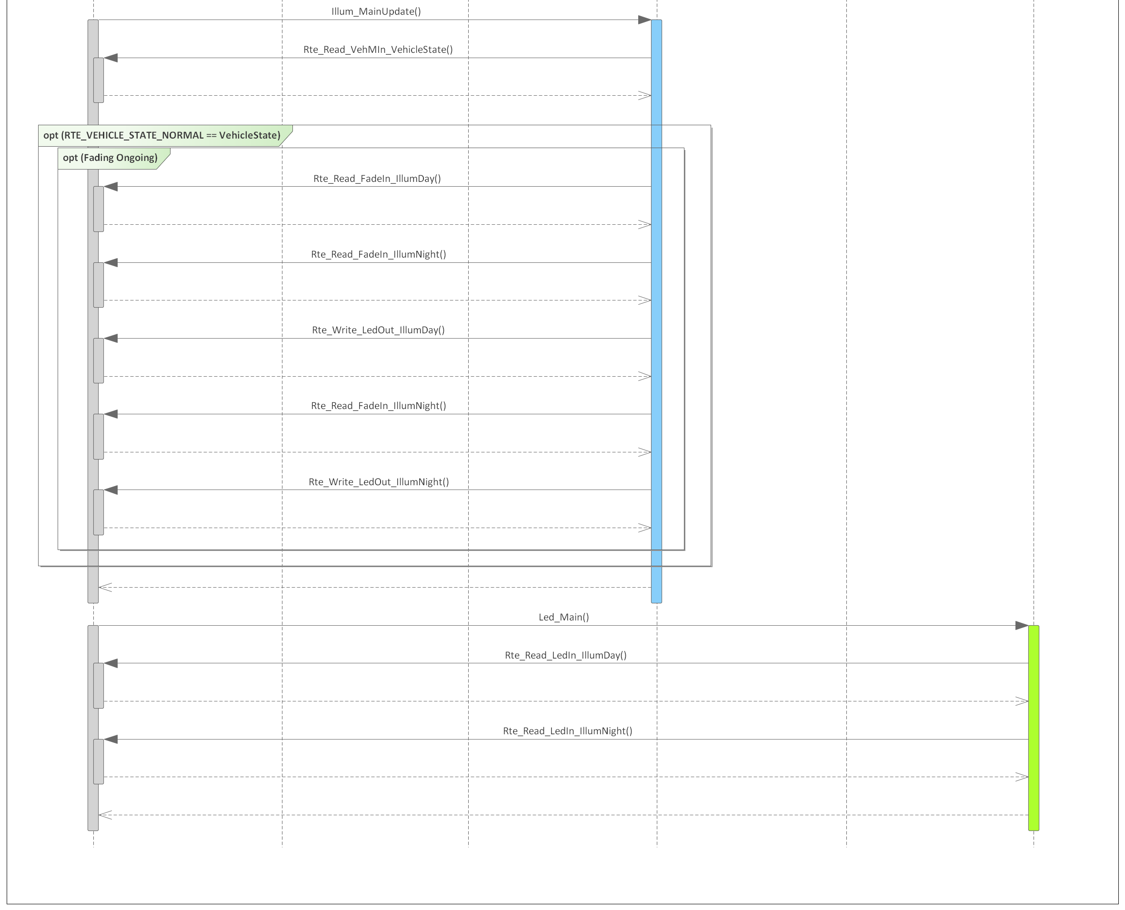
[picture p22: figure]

Figure 10 - Illumination runtime sequence diagram.

# 6 Information about this Document

## 1.1 Copyright

All rights, including translation rights, are reserved. Under no circumstances shall any fragment of this document be reproduced without written authorization from NTT DATA Romania S.A, including copying, photographing or replicating through other methods.

Copyright (c) NTT DATA Romania S.A.

## 1.2 Version Index

Version | Date | Author | Chapter | Modification description
1.0 | 10.07.2021 | Nicolae-Bogdan Bacrău | All | Created.

Table 2 - Version Index.

Copyright © NTT DATA Romania S.A. Page 8 of 22

Information Type: Working Standard Information Owner: Nicolae-Bogdan Bacrău Company: NTT DATA Romania

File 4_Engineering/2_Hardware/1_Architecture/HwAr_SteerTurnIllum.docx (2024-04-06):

Hardware Architecture

SteerTurnIllum


Author: | | Nicolae-Bogdan Bacrău
Version: | | 1.0

# Index

# 1 Glossary

This section contains a glossary of all the important terms and acronyms used inside the document.

Term / Acronym | Description
ECU | Electronic Control Unit
uC | Microcontroller
PWM | Pulse Width Modulation

Table 1 - Glossary.

# 2 Introduction

## Purpose of the Document

The purpose of the document is to define the hardware architecture of the SteerTurnIllum embedded academy project.

## Overview

The hardware architecture of SteerTurnIllum consists of the ECU schematic, which describes all the needed connections between the hardware components, and the microcontroller pin configurations which describes the pin modes and directions.

# 3 Schematic

The SteerTurnIllum ECU shall contain the following general hardware components:

- 1 x STM32F4DISCOVERY development board based on a STM32F407VG uC: STM32F407G-DISC1.
- 1 x pair of STM32F4DISCOVERY development board to breadboard adapters (not visible in the schematic since they are just connectors).
- resistors for pull-up, pull-down topologies and for current limitation.
- breadboards and wires for connecting all the hardware components.

The SteerTurnIllum ECU shall contain the following input hardware components:

- 3 x buttons for controlling the turn signals: BTN_LEFT, BTN_RIGHT, BTN_HAZARD.
- 1 x joystick with incorporated button for controlling the servomotors and the horn: JOY_STEER. The incorporated button represents BTN_HORN.
- 1 x potentiometer for controlling the luminance: POT_LUMINANCE.

The SteerTurnIllum ECU shall contain the following output hardware components:

- 1 x buzzer for indicating the activation of the horn: BUZZ_HORN.
- 4 x yellow LEDs for indicating the turn signals: LED_TURN_FRONT_LEFT, LED_TURN_FRONT_RIGHT, LED_TURN_BACK_LEFT, LED_TURN_BACK_RIGHT.
- 2 x red LEDs for indicating the board illumination: LED_ILLUM_NIGHT, LED_ILLUM_DAY.
- 1 x dual 7 segments display for indicating the configuration states: DISP7SEG.
- 1 x CD4050B buffer for amplifying the servomotor PWM signals: CD4050B.
- 2 x servomotors for indicating the steering of the wheels: SERVO_TURN_LEFT, SERVO_TURN_RIGHT.

The schematic of the ECU is presented in Figure 1. The schematic is also available as a .pdf in the ./../2_Schematic folder.

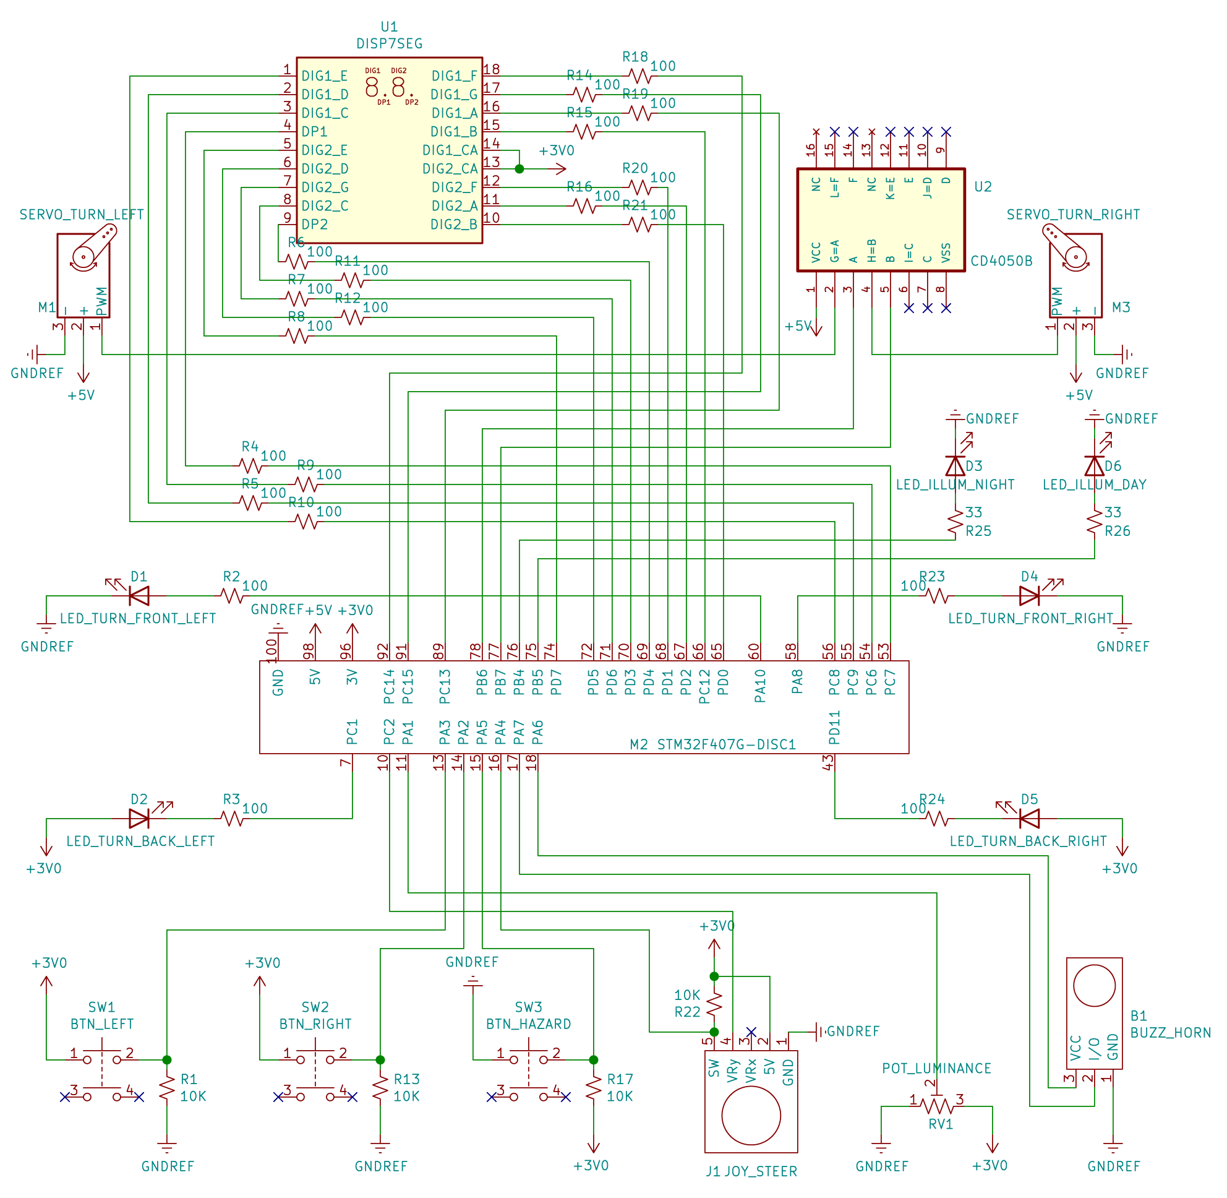
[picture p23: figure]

Figure 1 – ECU schematic.

# 4 Pin Configurations

The uC pin configurations that shall be used are presented in Table 2.

Pin Name | Pin Mode | Pin Direction | Peripheral
PA3 | Digital | In | BTN_LEFT
PA2 | Digital | In | BTN_RIGHT
PA5 | Digital | In | BTN_HAZARD
PA4 | Digital | In | JOY_STEER
PA7 | Digital | Out | BUZZ_HORN
PA6 | Digital | Out | BUZZ_HORN
PA10 | Digital | Out | LED_TURN_FRONT_LEFT
PA8 | Digital | Out | LED_TURN_FRONT_RIGHT
PC1 | Digital | Out | LED_TURN_BACK_LEFT
PD11 | Digital | Out | LED_TURN_BACK_RIGHT
PD0 | Digital | Out | DISP7SEG
PD2 | Digital | Out | DISP7SEG
PD1 | Digital | Out | DISP7SEG
PC12 | Digital | Out | DISP7SEG
PC13 | Digital | Out | DISP7SEG
PC15 | Digital | Out | DISP7SEG
PC14 | Digital | Out | DISP7SEG
PD4 | Digital | Out | DISP7SEG
PD3 | Digital | Out | DISP7SEG
PD6 | Digital | Out | DISP7SEG
PD5 | Digital | Out | DISP7SEG
PD7 | Digital | Out | DISP7SEG
PC7 | Digital | Out | DISP7SEG
PC6 | Digital | Out | DISP7SEG
PC9 | Digital | Out | DISP7SEG
PC8 | Digital | Out | DISP7SEG
PA1 | Analog | In | POT_LUMINANCE
PC2 | Analog | In | POT_LUMINANCE
PB4 | PWM | Out | LED_ILLUM_NIGHT
PB5 | PWM | Out | LED_ILLUM_DAY
PB6 | PWM | Out | SERVO_TURN_LEFT
PB7 | PWM | Out | SERVO_TURN_RIGHT

Table 2 - Pin configurations.

# 5 Information about this Document

## 1.1 Copyright

All rights, including translation rights, are reserved. Under no circumstances shall any fragment of this document be reproduced without written authorization from NTT DATA Romania S.A, including copying, photographing or replicating through other methods.

Copyright (c) NTT DATA Romania S.A.

## 1.2 Version Index

Vers. | Date | Author | Chapter | Modification description
1.0 | 10.07.2021 | Nicolae-Bogdan Bacrău | All | Created.

Table 3 - Version Index.

Copyright © NTT DATA Romania S.A. Page 9 of 9

Information Type: Working Standard Information Owner: Nicolae-Bogdan Bacrău Company: NTT DATA Romania

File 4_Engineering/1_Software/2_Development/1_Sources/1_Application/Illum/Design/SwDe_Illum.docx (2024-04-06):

Illum Software Design

SteerTurnIllum


Author: | | Nicolae-Bogdan Bacrău
Version: | | 1.0

# Index

# 1 Glossary

This section contains a glossary of all the important terms and acronyms used inside the document.

Term / Acronym | Description
AUTOSAR | AUTomotive Open System ARchitecture
VFB | Virtual Functional Bus
SWC | Software Component
RTE | Runtime Environment
BSW | Basic Software
OS | Operating System
S/R | Sender / Receiver
C/S | Client / Server
ECU | Electronic Control Unit
uC | Microcontroller
ADC | Analog Digital Converter
DIO | Digital Input / Output
PWM | Pulse Width Modulation

Table 1 - Glossary.

# 2 Introduction

## Purpose of the Document

The purpose of the document is to define the software design of the Illum SWC for the SteerTurnIllum embedded academy project.

## Overview

The Illum SWC implements the control of the day and night illumination LEDs through fading jobs based on the modifications in the ambient luminance.

# 3 Design Requirements

[SWDE_ILLUM_1] The Illum SWC shall adhere to the structure illustrated in the composite structure diagram from Figure 1.

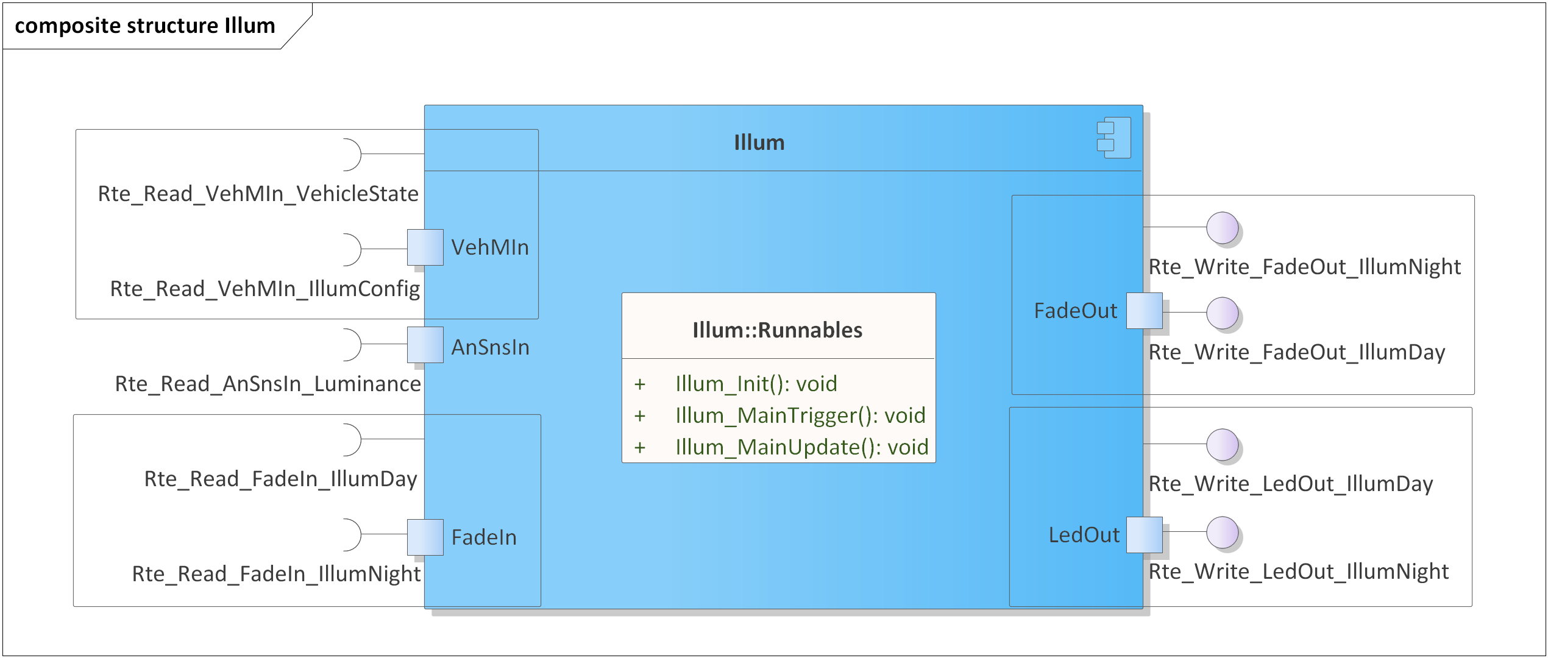
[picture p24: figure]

Figure 1 - Illum composite structure diagram.

[SWDE_ILLUM_2] The Illum SWC shall implement the illumination requirements as described in chapter 4.5 from the System Requirements.
[SWDE_ILLUM_3] The Illum SWC shall be implemented in two C files: Illum.h for exporting all the runnables, and Illum.c for implementing the runnables.
[SWDE_ILLUM_4] The Illum SWC shall implement the void Illum_Init(void) runnable for initializing all the internal static and global variables.
[SWDE_ILLUM_5] The Illum SWC shall implement the void Illum_MainTrigger(void) runnable for:
- Reading the ambient luminance through Rte_Read_AnSnsIn_Luminance().
- Averaging the read ambient luminance.
- Reading the current illumination configuration through Rte_Read_VehMIn_IllumConfig().
- Identifying fading triggers based on the modifications in the ambient luminance and starting fading jobs through Rte_Write_FadeOut_*() with fading times depending on the read illumination configuration.
[SWDE_ILLUM_6] The Illum SWC shall implement the void Illum_MainUpdate(void) runnable for reading the current status of the fading jobs, through Rte_Read_FadeIn_*() and updating the duty cycles of the illumination LEDs, through Rte_Write_LedOut_*(), with the read fading levels.
[SWDE_ILLUM_7] The Rte_Write_FadeOut_*() start and target values and the Rte_Write_LedOut_*() duty cycle values shall be in the [0, 10000] interval, representing PWM duty cycle percentages with two decimals.
[SWDE_ILLUM_8] The Illum SWC shall include Efx.h and directly use the Efx_MovingAverage_u16_u16() function for averaging the ambient luminance.
[SWDE_ILLUM_9] The Illum SWC shall include Ifx.h and directly use the Ifx_IntIpoCur_u16_u16() function for calculating duty cycles based on the average luminance.
[SWDE_ILLUM_10] Illum_MainUpdate() and Illum_MainTrigger() shall execute only if the current vehicle state, read through Rte_Read_VehMIn_VehicleState(), is RTE_VEHICLE_STATE_NORMAL.

# 4 Information about this Document

## 1.1 Copyright

All rights, including translation rights, are reserved. Under no circumstances shall any fragment of this document be reproduced without written authorization from NTT DATA Romania S.A, including copying, photographing or replicating through other methods.

Copyright (c) NTT DATA Romania S.A.

## 1.2 Version Index

Version | Date | Author | Chapter | Modification description
1.0 | 10.07.2021 | Nicolae-Bogdan Bacrău | All | Created.

Table 2 - Version Index.

Copyright © NTT DATA Romania S.A. Page 8 of 22

Information Type: Working Standard Information Owner: Nicolae-Bogdan Bacrău Company: NTT DATA Romania

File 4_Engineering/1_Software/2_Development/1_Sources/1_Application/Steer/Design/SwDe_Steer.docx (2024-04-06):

Steer Software Design

SteerTurnIllum


Author: | | Nicolae-Bogdan Bacrău
Version: | | 1.0

# Index

# 1 Glossary

This section contains a glossary of all the important terms and acronyms used inside the document.

Term / Acronym | Description
AUTOSAR | AUTomotive Open System ARchitecture
VFB | Virtual Functional Bus
SWC | Software Component
RTE | Runtime Environment
BSW | Basic Software
OS | Operating System
S/R | Sender / Receiver
C/S | Client / Server
ECU | Electronic Control Unit
uC | Microcontroller
ADC | Analog Digital Converter
DIO | Digital Input / Output
PWM | Pulse Width Modulation

Table 1 - Glossary.

# 2 Introduction

## Purpose of the Document

The purpose of the document is to define the software design of the Steer SWC for the SteerTurnIllum embedded academy project.

## Overview

The Steer SWC implements the control of the steering servomotors based on the movements of the steering joystick and the control of the steering horn based on the presses of the horn button.

# 3 Design Requirements

[SWDE_STEER_1] The Steer SWC shall adhere to the structure illustrated in the composite structure diagram from Figure 1.


Figure 1 - Steer composite structure diagram.

[SWDE_STEER_2] The Steer SWC shall implement the steering requirements as described in chapter 4.3 from the System Requirements.
[SWDE_STEER_3] The Steer SWC shall be implemented in two C files: Steer.h for exporting all the runnables, and Steer.c for implementing the runnables.
[SWDE_STEER_4] The Steer SWC shall implement the void Steer_Init(void) runnable for initializing all the internal static and global variables.
[SWDE_STEER_5] The Steer SWC shall implement the void Steer_MainTrigger(void) runnable for:
- Reading the press state of the horn button through Rte_Read_BtnIn_Horn().
- Reading the current horn configuration through Rte_Read_VehMIn_HornConfig().
- If the horn button is pressed, process horn activation based on the read horn configuration:
  - RTE_HORN_MODE_CONTINUOUS: set horn state to STEER_HORN_CONTROL_CONTINUOUS.
  - RTE_HORN_MODE_BEEPING: set horn state to STEER_HORN_CONTROL_BEEPING and trigger continuous SwPwm job through Rte_Write_SwPwmOut_Horn().
- If the horn button is not pressed, set horn state to STEER_HORN_CONTROL_MUTE.
[SWDE_STEER_6] The Steer SWC shall implement the void Steer_MainUpdate(void) runnable for:
- Controlling the buzzer activation, through Rte_Write_BuzzOut_Horn(), based on the current horn state:
  - STEER_HORN_CONTROL_MUTE: apply RTE_BUZZ_OFF.
  - STEER_HORN_CONTROL_CONTINUOUS: apply RTE_BUZZ_ON.
  - STEER_HORN_CONTROL_BEEPING: read and apply current value from the SwPwm job, through Rte_Read_SwPwmIn_Horn().
- Reading the current steering configuration through Rte_Read_VehMIn_SteerConfig().
- Reading the current steering joystick position through Rte_Read_AnSnsIn_Steer().
- Calculate the inner and outer angles of the servomotors based on the current steering configuration and current position of the steering joystick.
- Transform the calculated inner and outer angles in absolute angles and set them through Rte_Write_ServoOut_*().
[SWDE_STEER_7] The Rte_Write_ServoOut_*() absolute angle values shall be in the [0 ... 18000] interval, representing desired angles with two decimals (0 meaning pointing right, 9000 meaning pointing forward and 18000 meaning pointing left).
[SWDE_STEER_8] Steer_MainUpdate() and Steer_MainTrigger() shall execute only if the current vehicle state, read through Rte_Read_VehMIn_VehicleState(), is RTE_VEHICLE_STATE_NORMAL.

# 4 Information about this Document

## 1.1 Copyright

All rights, including translation rights, are reserved. Under no circumstances shall any fragment of this document be reproduced without written authorization from NTT DATA Romania S.A, including copying, photographing or replicating through other methods.

Copyright (c) NTT DATA Romania S.A.

## 1.2 Version Index

Version | Date | Author | Chapter | Modification description
1.0 | 10.07.2021 | Nicolae-Bogdan Bacrău | All | Created.

Table 2 - Version Index.

Copyright © NTT DATA Romania S.A. Page 8 of 22

Information Type: Working Standard Information Owner: Nicolae-Bogdan Bacrău Company: NTT DATA Romania

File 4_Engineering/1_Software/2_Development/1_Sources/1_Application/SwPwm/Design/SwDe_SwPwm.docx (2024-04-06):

SwPwm Software Design

SteerTurnIllum


Author: | | Nicolae-Bogdan Bacrău
Version: | | 1.0

# Index

# 1 Glossary

This section contains a glossary of all the important terms and acronyms used inside the document.

Term / Acronym | Description
AUTOSAR | AUTomotive Open System ARchitecture
VFB | Virtual Functional Bus
SWC | Software Component
RTE | Runtime Environment
BSW | Basic Software
OS | Operating System
S/R | Sender / Receiver
C/S | Client / Server
ECU | Electronic Control Unit
uC | Microcontroller
ADC | Analog Digital Converter
DIO | Digital Input / Output
PWM | Pulse Width Modulation

Table 1 - Glossary.

# 2 Introduction

## Purpose of the Document

The purpose of the document is to define the software design of the SwPwm SWC for the SteerTurnIllum embedded academy project.

## Overview

The SwPwm SWC generates software PWMs by keeping track of the elapsed time through a cyclic task. It is able to generate continuous software PWMs (generated until specifically stopped) and finite software PWMs (automatic stop after a given number of periods).

SwPwm is an application SWC, so it has no access to MCAL resources for writing actual signals. It just provides digital software output values to be used for generating actual signals.

# 3 Design Requirements

[SWDE_SWPWM_1] The SwPwm SWC shall adhere to the structure illustrated in the composite structure diagram from Figure 1.


Figure 1 - SwPwm composite structure diagram.

[SWDE_SWPWM_2] The SwPwm SWC shall adhere to the SWC file structure template from 4_Engineering\1_Software\2_Development\1_Sources\8_Templates\Swc\Code.
[SWDE_SWPWM_3] The SwPwm SWC shall contain the following configuration parameters:
- In SwPwm_Cfg.h:
  - SWPWM_MAIN_PERIODICITY_US: macro defining the periodicity of the main function in microseconds.
  - SWPWM_NUMBER_OF_INSTANCES: macro defining the number of software PWM instances to be processed in the main function.
  - SWPWM_*_INSTANCE: zero based macros defining unique IDs of all the software PWM instances, needed for the interaction between the core and RTE.
- In SwPwm_Cfg.c:
  - Rte_SwPwmLevelType SwPwm_gkat_Config[SWPWM_NUMBER_OF_INSTANCES]: internal global constant array defining the active values to be used at the start of each period (STD_HIGH or STD_LOW) for all the software PWM instances.
[SWDE_SWPWM_4] The SwPwm SWC shall implement the void SwPwm_Init(void) runnable for initializing all the internal static and global variables.
[SWDE_SWPWM_5] The SwPwm SWC shall implement the void SwPwm_Main(void) runnable for implementing the processing of all the software PWM jobs as follows:
- Checks if the software PWM input control data elements have been updated, through Rte_IsUpdated_SwPwmIn_*(), and, if true, reads the input control data through Rte_Read_SwPwmIn_*() and starts a new job for that channel.
- If a job is ongoing, updates the output status data and writes it to RTE through Rte_Write_PwmOut_*().
- If a job is ongoing and the input control data has been updated, the current job shall be aborted and a new one shall be started with the new data.
- Depending on the input control data, the behavior shall be as follows:
  - RTE_SWPWM_OFF: continuously reporting the output level as the inverse of the configured active level and the number of periods left always set to 0.
  - RTE_SWPWM_ON_CONTINUOUS: keeping track of the elapsed time and continuously generating the output level according to the configured active level, the input control period and the active time, while the number of periods left is always set to 0.
  - RTE_SWPWM_FINITE: keeping track of the elapsed time, generating the output according to the configured active level, the input control period and the active time, and automatically switching to RTE_SWPWM_OFF after the number of periods left reaches 0.

# 4 Information about this Document

## 1.1 Copyright

All rights, including translation rights, are reserved. Under no circumstances shall any fragment of this document be reproduced without written authorization from NTT DATA Romania S.A, including copying, photographing or replicating through other methods.

Copyright (c) NTT DATA Romania S.A.

## 1.2 Version Index

Version | Date | Author | Chapter | Modification description
1.0 | 10.07.2021 | Nicolae-Bogdan Bacrău | All | Created.

Table 2 - Version Index.

Copyright © NTT DATA Romania S.A. Page 8 of 22

Information Type: Working Standard Information Owner: Nicolae-Bogdan Bacrău Company: NTT DATA Romania

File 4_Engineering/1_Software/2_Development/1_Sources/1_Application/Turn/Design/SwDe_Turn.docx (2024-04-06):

Turn Software Design

SteerTurnIllum


Author: | | Nicolae-Bogdan Bacrău
Version: | | 1.0

# Index

# 1 Glossary

This section contains a glossary of all the important terms and acronyms used inside the document.

Term / Acronym | Description
AUTOSAR | AUTomotive Open System ARchitecture
VFB | Virtual Functional Bus
SWC | Software Component
RTE | Runtime Environment
BSW | Basic Software
OS | Operating System
S/R | Sender / Receiver
C/S | Client / Server
ECU | Electronic Control Unit
uC | Microcontroller
ADC | Analog Digital Converter
DIO | Digital Input / Output
PWM | Pulse Width Modulation

Table 1 - Glossary.

# 2 Introduction

## Purpose of the Document

The purpose of the document is to define the software design of the Turn SWC for the SteerTurnIllum embedded academy project.

## Overview

The Turn SWC implements the control of the turn indication LEDs based on the presses of the left turning, right turning and hazard buttons.

# 3 Design Requirements

[SWDE_TURN_1] The Turn SWC shall adhere to the structure illustrated in the composite structure diagram from Figure 1.


Figure 1 - Turn composite structure diagram.

[SWDE_TURN_2] The Turn SWC shall implement the turning requirements as described in chapter 4.4w from the System Requirements.
[SWDE_TURN_3] The Turn SWC shall be implemented in two C files: Turn.h for exporting all the runnables, and Turn.c for implementing the runnables.
[SWDE_TURN_4] The Turn SWC shall implement the void Turn_Init(void) runnable for initializing all the internal static and global variables.
[SWDE_TURN_5] The Turn SWC shall implement the void Turn_MainTrigger(void) runnable for:
- Reading the press state of the left turning, right turning and hazard buttons through Rte_Read_BtnIn_*().
- Reading the current turn configuration through Rte_Read_VehMIn_TurnConfig().
- Reading the steering joystick position through Rte_Read_AnSnsIn_Steer().
- Identifying the short and long button triggers as well as the joystick steering triggers for performing transitions between the turning states.
- Starting a new SwPwm job, through Rte_Write_SwPwmOut_Turn(), when performing state transitions.
[SWDE_TURN_6] The Turn SWC shall implement the void Turn_MainUpdate(void) runnable for writing the indication LEDs control data, through Rte_Write_LedOut_*(), based on the current turning state and on the SwPwm job status, read through Rte_Read_SwPwmIn_Turn().

# 4 Information about this Document

## 1.1 Copyright

All rights, including translation rights, are reserved. Under no circumstances shall any fragment of this document be reproduced without written authorization from NTT DATA Romania S.A, including copying, photographing or replicating through other methods.

Copyright (c) NTT DATA Romania S.A.

## 1.2 Version Index

Version | Date | Author | Chapter | Modification description
1.0 | 10.07.2021 | Nicolae-Bogdan Bacrău | All | Created.

Table 2 - Version Index.

Copyright © NTT DATA Romania S.A. Page 8 of 22

Information Type: Working Standard Information Owner: Nicolae-Bogdan Bacrău Company: NTT DATA Romania

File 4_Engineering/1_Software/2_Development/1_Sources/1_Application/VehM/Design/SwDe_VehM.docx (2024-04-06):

VehM Software Design

SteerTurnIllum


Author: | | Nicolae-Bogdan Bacrău
Version: | | 1.0

# Index

# 1 Glossary

This section contains a glossary of all the important terms and acronyms used inside the document.

Term / Acronym | Description
AUTOSAR | AUTomotive Open System ARchitecture
VFB | Virtual Functional Bus
SWC | Software Component
RTE | Runtime Environment
BSW | Basic Software
OS | Operating System
S/R | Sender / Receiver
C/S | Client / Server
ECU | Electronic Control Unit
uC | Microcontroller
ADC | Analog Digital Converter
DIO | Digital Input / Output
PWM | Pulse Width Modulation

Table 1 - Glossary.

# 2 Introduction

## Purpose of the Document

The purpose of the document is to define the software design of the VehM SWC for the SteerTurnIllum embedded academy project.

## Overview

The VehM SWC implements the control of the vehicle states (NORMAL or CONFIGURATION) and the control of the configuration menu while in the CONFIGURATION state.

# 3 Design Requirements

[SWDE_VEHM_1] The VehM SWC shall adhere to the structure illustrated in the composite structure diagram from Figure 1.


Figure 1 - VehM composite structure diagram.

[SWDE_VEHM_2] The VehM SWC shall implement the vehicle management requirements as described in chapter 4.2 from the System Requirements.
[SWDE_VEHM_3] The VehM SWC shall be implemented in two C files: VehM.h for exporting all the runnables, and VehM.c for implementing the runnables.
[SWDE_VEHM_4] The VehM SWC shall implement the void VehM_Init(void) runnable for initializing all the internal static and global variables.
[SWDE_VEHM_5] The VehM SWC shall implement the void VehM_Main(void) runnable for:
- Reading the press state of all the buttons, through Rte_Read_BtnIn_*(), and the luminance potentiometer, through Rte_Read_AnSnsIn_Luminance().
- Checking the trigger for performing the transition between the RTE_VEHICLE_STATE_NORMAL and RTE_VEHICLE_STATE_CONFIG states and writing the current vehicle state through Rte_Write_VehMOut_VehicleState().
- If in the RTE_VEHICLE_STATE_CONFIG state:
  - Setting default control values for the servomotors and buzzer through Rte_Write_ServoOut_*() and Rte_Write_BuzzOut_Horn().
  - Identifying the triggers of left turning, right turning and hazard buttons and perform the transitions between the CONFIGURATION states.
  - Display the current state on the indication LEDs through Rte_Write_LedOut_Turn*().
  - Display the current substate on the illumination LEDs through Rte_Write_LedOut_Illum*().
  - Display the current configuration value for the current configuration state and substate on the 7 segments display through Rte_Write_Disp7SegOut_User().
  - Save the current configuration value for the current configuration state and substate through Rte_Write_VehMOut_*Config() when the horn button is pressed.

# 4 Information about this Document

## 1.1 Copyright

All rights, including translation rights, are reserved. Under no circumstances shall any fragment of this document be reproduced without written authorization from NTT DATA Romania S.A, including copying, photographing or replicating through other methods.

Copyright (c) NTT DATA Romania S.A.

## 1.2 Version Index

Version | Date | Author | Chapter | Modification description
1.0 | 10.07.2021 | Nicolae-Bogdan Bacrău | All | Created.

Table 2 - Version Index.

Copyright © NTT DATA Romania S.A. Page 8 of 22

Information Type: Working Standard Information Owner: Nicolae-Bogdan Bacrău Company: NTT DATA Romania

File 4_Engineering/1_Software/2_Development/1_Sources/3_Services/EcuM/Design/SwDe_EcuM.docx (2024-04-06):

EcuM Software Design

SteerTurnIllum


Author: | | Nicolae-Bogdan Bacrău
Version: | | 1.0

# Index

# 1 Glossary

This section contains a glossary of all the important terms and acronyms used inside the document.

Term / Acronym | Description
AUTOSAR | AUTomotive Open System ARchitecture
VFB | Virtual Functional Bus
SWC | Software Component
RTE | Runtime Environment
BSW | Basic Software
OS | Operating System
S/R | Sender / Receiver
C/S | Client / Server
ECU | Electronic Control Unit
uC | Microcontroller
ADC | Analog Digital Converter
DIO | Digital Input / Output
PWM | Pulse Width Modulation

Table 1 - Glossary.

# 2 Introduction

## Purpose of the Document

The purpose of the document is to define the software design of the EcuM for the SteerTurnIllum embedded academy project.

## Overview

While the AUTOSAR EcuM module is complex and is usually configured via generators, in this project its purpose is limited to initializing the MCAL drivers and starting the OS.

# 3 Design Requirements

[SWDE_ECUM_1] EcuM shall assure initialization of all MCAL drivers in EcuM_AL_DriverInitOne() from EcuM_Callout_Stubs.c. The EcuM_Callout_Stubs.c.start file shall be used as a starting point. The .start extension shall be removed for adding the file to the build process.

Note: This update should take place after the Mcu, Adc, Dio, Port and Pwm drivers have been fully implemented and tested.

# 4 Information about this Document

## 1.1 Copyright

All rights, including translation rights, are reserved. Under no circumstances shall any fragment of this document be reproduced without written authorization from NTT DATA Romania S.A, including copying, photographing or replicating through other methods.

Copyright (c) NTT DATA Romania S.A.

## 1.2 Version Index

Version | Date | Author | Chapter | Modification description
1.0 | 10.07.2021 | Nicolae-Bogdan Bacrău | All | Created.

Table 2 - Version Index.

Copyright © NTT DATA Romania S.A. Page 6 of 7

Information Type: Working Standard Information Owner: Nicolae-Bogdan Bacrău Company: NTT DATA Romania

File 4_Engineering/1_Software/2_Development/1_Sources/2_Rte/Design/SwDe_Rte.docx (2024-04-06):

Rte Software Design

SteerTurnIllum


Author: | | Nicolae-Bogdan Bacrău
Version: | | 1.0

# Index

# 1 Glossary

This section contains a glossary of all the important terms and acronyms used inside the document.

Term / Acronym | Description
AUTOSAR | AUTomotive Open System ARchitecture
VFB | Virtual Functional Bus
SWC | Software Component
RTE | Runtime Environment
BSW | Basic Software
OS | Operating System
S/R | Sender / Receiver
C/S | Client / Server
ECU | Electronic Control Unit
uC | Microcontroller
ADC | Analog Digital Converter
DIO | Digital Input / Output
PWM | Pulse Width Modulation

Table 1 - Glossary.

# 2 Introduction

## Purpose of the Document

The purpose of the document is to define the software design of the Rte for the SteerTurnIllum embedded academy project.

## Overview

While the AUTOSAR Rte module is complex and is usually configured via generators, in this project it is manually implemented and contains the following:

- Execution of runnables inside OS tasks.
- S/R interfaces for the communication between the SWCs.

# 3 Design Requirements

[SWDE_RTE_1] Rte shall assure initialization values for all S/R buffers declared in Rte_Buffers.c according to the System Requirements.
[SWDE_RTE_2] All initializations shall take place in Rte_Start() from Rte.c. The Rte.c.start file shall be used as a starting point. The .start extension shall be removed for adding the file to the build process.
[SWDE_RTE_3] Rte shall assure the implementation of all OS tasks according to timing requirements from the System Requirements and execution flow from the runtime sequence diagrams from the Software Architecture.
[SWDE_RTE_4] All OS tasks, TASK(OS_*_TASK), shall be implemented in Rte_Tasks.c. The Rte_Tasks.c.start file shall be used as a starting point. The .start extension shall be removed for adding the file to the build process.

Note: Some of the SWCs runnables keep track of the time through the periodicity of the main function they are executed in. The configured periodicities for all such SWCs runnables inside the provided SWC libraries are:

- Btn_Main() : 1 ms.
- Turn_MainTrigger() : 5 ms.
- Turn_MainUpdate() : 5 ms.
- SwPwm_Main() : 5 ms.
- Fade_Main() : 10 ms.

# 4 Information about this Document

## 1.1 Copyright

All rights, including translation rights, are reserved. Under no circumstances shall any fragment of this document be reproduced without written authorization from NTT DATA Romania S.A, including copying, photographing or replicating through other methods.

Copyright (c) NTT DATA Romania S.A.

## 1.2 Version Index

Version | Date | Author | Chapter | Modification description
1.0 | 10.07.2021 | Nicolae-Bogdan Bacrău | All | Created.

Table 2 - Version Index.

Copyright © NTT DATA Romania S.A. Page 6 of 7

Information Type: Working Standard Information Owner: Nicolae-Bogdan Bacrău Company: NTT DATA Romania

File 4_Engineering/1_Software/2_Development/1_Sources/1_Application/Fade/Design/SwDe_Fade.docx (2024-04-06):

Fade Software Design

SteerTurnIllum


Author: | | Nicolae-Bogdan Bacrău
Version: | | 1.0

# Index

# 1 Glossary

This section contains a glossary of all the important terms and acronyms used inside the document.

Term / Acronym | Description
AUTOSAR | AUTomotive Open System ARchitecture
VFB | Virtual Functional Bus
SWC | Software Component
RTE | Runtime Environment
BSW | Basic Software
OS | Operating System
S/R | Sender / Receiver
C/S | Client / Server
ECU | Electronic Control Unit
uC | Microcontroller
ADC | Analog Digital Converter
DIO | Digital Input / Output
PWM | Pulse Width Modulation

Table 1 - Glossary.

# 2 Introduction

## Purpose of the Document

The purpose of the document is to define the software design of the Fade SWC for the SteerTurnIllum embedded academy project.

## Overview

The Fade SWC implements a mechanism for performing a transition between a start value and a target value in a given amount of time by following a function that is defined through linear equations.

# 3 Design Requirements

[SWDE_FADE_1] The Fade SWC shall adhere to the structure illustrated in the composite structure diagram from Figure 1.


Figure 1 - Fade composite structure diagram.

[SWDE_FADE_2] The Fade SWC shall implement the fading mechanism as described in chapter 3.4 from the System Requirements.
[SWDE_FADE_3] The Fade SWC shall adhere to the SWC file structure template from 4_Engineering\1_Software\2_Development\1_Sources\8_Templates\Swc\Code.
[SWDE_FADE_4] The Fade SWC shall contain the following configuration parameters:
- In Fade_Cfg.h:
  - FADE_MAIN_PERIODICITY_US: macro defining the periodicity of the main function in microseconds.
  - FADE_NUMBER_OF_INSTANCES: macro defining the number of fading instances to be processed in the main function.
  - FADE_*_INSTANCE: zero based macros defining unique IDs of all the fading instances, needed for the interaction between the core and RTE.
- In Fade_Cfg.c:
  - Fade_gkat_Config[FADE_NUMBER_OF_INSTANCES]: internal global constant array defining the IFX interpolation curve configurations for all the instances.
[SWDE_FADE_5] The Fade SWC shall configure the IFX interpolation points, needed for Fade_gkat_Config[], defined on columns F and G in .\Resources\SwDe_Fade_Config.xlsx.
[SWDE_FADE_6] The Fade SWC shall implement the void Fade_Init(void) runnable for initializing all the internal static and global variables.
[SWDE_FADE_7] The Fade SWC shall implement the void Fade_Main(void) runnable for implementing the processing of all the fading jobs as follows:
- Checks if the fading input control data elements have been updated, through Rte_IsUpdated_FadeIn_*(), and, if true, reads the input control data through Rte_Read_FadeIn_*() and starts a new fading job.
- If a fading job is ongoing, updates the output fading status data and writes it to RTE through Rte_Write_FadeOut_*().
- If a fading job is ongoing and the fading input control data has been updated, the current job shall be aborted and a new one shall be started with the new data.
- Once the elapsed time reaches 0, and implicitly the target value has been reached, the fading job shall enter the idle state.
- While in the idle state, the output fading status data shall remain unchanged.
- If the input control data contains the input fading time equal to 0 or if the start value equals the target value, the output level shall be set to the target level and the fading job shall immediately enter the idle state.
[SWDE_FADE_8] The Fade SWC shall include Ifx.h and directly use the Ifx_IntIpoCur_u16_u16() function for calculating the current output level through linear interpolation.

# 4 Information about this Document

## 1.1 Copyright

All rights, including translation rights, are reserved. Under no circumstances shall any fragment of this document be reproduced without written authorization from NTT DATA Romania S.A, including copying, photographing or replicating through other methods.

Copyright (c) NTT DATA Romania S.A.

## 1.2 Version Index

Version | Date | Author | Chapter | Modification description
1.0 | 10.07.2021 | Nicolae-Bogdan Bacrău | All | Created.

Table 2 - Version Index.

Copyright © NTT DATA Romania S.A. Page 8 of 22

Information Type: Working Standard Information Owner: Nicolae-Bogdan Bacrău Company: NTT DATA Romania

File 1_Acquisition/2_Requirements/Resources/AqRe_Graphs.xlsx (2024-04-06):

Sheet: Ackermann
𝛿𝑖 | 𝛿o
0.1 | 0.09991280971
1 | 0.9913497125
2 | 1.965705657
3 | 2.923530293
4 | 3.865287692
5 | 4.791441983
10 | 9.204256079
15 | 13.29468619
20 | 17.11523801
25 | 20.71372701
30 | 24.13326121
35 | 27.41271688
40 | 30.58744531
45 | 33.69006753
50 | 36.75128768
55 | 39.8006982
60 | 42.86757315

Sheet: Fading
X [0..1] | Y[0..1] | X [0..100]% | Y [0..100]% | 0%->30% @ 150ms
0 | 0.000000 | 0.00 | 0.00 | 150 | 0
0.005 | 6.25e-10 | 0.50 | 6.25e-08 | 140 | 0
0.01 | 1e-08 | 1.00 | 1e-06 | 130 | 0
0.015 | 5.0625e-08 | 1.50 | 5.0625e-06 | 120 | 0.04
0.02 | 1.6e-07 | 2.00 | 1.6e-05 | 110 | 0.15
0.025 | 3.90625e-07 | 2.50 | 3.90625e-05 | 100 | 0.37
0.03 | 0.000001 | 3.00 | 8.1e-05 | 90 | 0.77
0.035 | 0.000002 | 3.50 | 0.0001500625 | 80 | 1.42
0.04 | 0.000003 | 4.00 | 0.000256 | 70 | 2.43
0.045 | 0.000004 | 4.50 | 0.0004100625 | 60 | 3.89
0.05 | 0.000006 | 5.00 | 0.000625 | 50 | 5.93
0.055 | 0.000009 | 5.50 | 0.0009150625 | 40 | 8.68
0.06 | 0.000013 | 6.00 | 0.001296 | 30 | 12.29
0.065 | 0.000018 | 6.50 | 0.0017850625 | 20 | 16.92
0.07 | 0.000024 | 7.00 | 0.002401 | 10 | 22.75
0.075 | 0.000032 | 7.50 | 0.0031640625 | 0 | 30
0.08 | 0.000041 | 8.00 | 0.004096
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

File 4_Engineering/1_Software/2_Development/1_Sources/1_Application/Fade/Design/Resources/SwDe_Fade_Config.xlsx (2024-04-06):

X [0..1] | Y[0..1] | X [0..10000] | Y [0..10000] | X [0..10000] | Y [0..10000]
0 | 0.000000 | 0 | 0 | 0 | 0
0.005 | 6.25e-10 | 50 | 0 | 1000 | 1
0.01 | 1e-08 | 100 | 0 | 1250 | 2
0.015 | 5.0625e-08 | 150 | 0 | 1500 | 5
0.02 | 1.6e-07 | 200 | 0 | 1750 | 9
0.025 | 3.90625e-07 | 250 | 0 | 2000 | 16
0.03 | 0.000001 | 300 | 0 | 2250 | 25
0.035 | 0.000002 | 350 | 0 | 2500 | 39
0.04 | 0.000003 | 400 | 0 | 2750 | 57
0.045 | 0.000004 | 450 | 0 | 3000 | 81
0.05 | 0.000006 | 500 | 0 | 3250 | 111
0.055 | 0.000009 | 550 | 0 | 3500 | 150
0.06 | 0.000013 | 600 | 0 | 3750 | 197
0.065 | 0.000018 | 650 | 0 | 4000 | 256
0.07 | 0.000024 | 700 | 0 | 4250 | 326
0.075 | 0.000032 | 750 | 0 | 4500 | 410
0.08 | 0.000041 | 800 | 0 | 4750 | 509
0.085 | 0.000052 | 850 | 0 | 5000 | 625
0.09 | 0.000066 | 900 | 0 | 5250 | 759
0.095 | 0.000081 | 950 | 0 | 5500 | 915
0.1 | 0.000100 | 1000 | 1 | 5750 | 1093
0.105 | 0.000122 | 1050 | 1 | 6000 | 1296
0.11 | 0.000146 | 1100 | 1 | 6250 | 1525
0.115 | 0.000175 | 1150 | 1 | 6500 | 1785
0.12 | 0.000207 | 1200 | 2 | 6750 | 2075
0.125 | 0.000244 | 1250 | 2 | 7000 | 2401
0.13 | 0.000286 | 1300 | 2 | 7250 | 2762
0.135 | 0.000332 | 1350 | 3 | 7500 | 3164
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

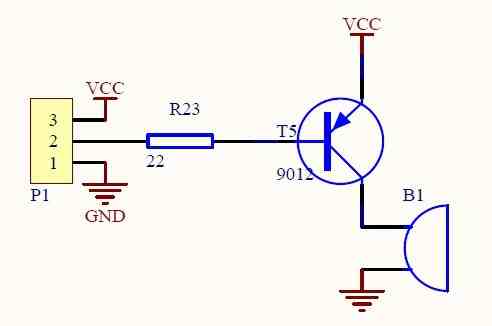
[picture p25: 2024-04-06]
4_Engineering/2_Hardware/3_Datasheets/Buzzer/Buzzer.jpg

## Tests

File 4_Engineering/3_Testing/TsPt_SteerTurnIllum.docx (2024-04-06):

Testing Protocol

SteerTurnIllum


Author: | | Alexandru-Sebastian Anghel
Version: | | 1.0

# Index

# 1 Glossary

This section contains a glossary of all the important terms and acronyms used inside the document.

Term / Acronym | Description
uC | Microcontroller
PWM | Pulse-Width Modulation
ms | milliseconds

Table 1 - Glossary.

# 2 Introduction

## Purpose of the Document

The purpose of the document is to define the testing protocol of the SteerTurnIllum embedded academy project.

## Overview

All the functionalities of this project are described in ‘AqRe_SteerTurnIllum’ document which can be found at 1_Acquisition\2_Requirements.

# 3 Testing procedure

Those tests shall be performed after every new implementation in order to check if the functionalities of the project are still available. It is mandatory to follow this procedure before any review meeting.

Components required:

- Eclipse IDE
- uC & other peripherals
- .elf file generated from project build
- Project pinout configuration

The uC pin configurations that shall be used are presented in Table 2.

Pin Name | Pin Mode | Pin Direction | Peripheral
PA3 | Digital | In | BTN_LEFT
PA2 | Digital | In | BTN_RIGHT
PA5 | Digital | In | BTN_HAZARD
PA4 | Digital | In | JOY_STEER
PA7 | Digital | Out | BUZZ_HORN
PA6 | Digital | Out | BUZZ_HORN
PC2 | Digital | In | BUZZ_BTN
PA10 | Digital | Out | LED_TURN_FRONT_LEFT
PA8 | Digital | Out | LED_TURN_FRONT_RIGHT
PC1 | Digital | Out | LED_TURN_BACK_LEFT
PD11 | Digital | Out | LED_TURN_BACK_RIGHT
PD0 | Digital | Out | DISP7SEG
PD2 | Digital | Out | DISP7SEG
PD1 | Digital | Out | DISP7SEG
PC12 | Digital | Out | DISP7SEG
PC13 | Digital | Out | DISP7SEG
PC15 | Digital | Out | DISP7SEG
PC14 | Digital | Out | DISP7SEG
PD4 | Digital | Out | DISP7SEG
PD3 | Digital | Out | DISP7SEG
PD6 | Digital | Out | DISP7SEG
PD5 | Digital | Out | DISP7SEG
PD7 | Digital | Out | DISP7SEG
PC7 | Digital | Out | DISP7SEG
PC6 | Digital | Out | DISP7SEG
PC9 | Digital | Out | DISP7SEG
PC8 | Digital | Out | DISP7SEG
PA1 | Analog | In | POT_LUMINANCE
PB4 | PWM | Out | LED_ILLUM_NIGHT
PB5 | PWM | Out | LED_ILLUM_DAY
PB6 | PWM | Out | SERVO_TURN_LEFT
PB7 | PWM | Out | SERVO_TURN_RIGHT

Table 2 - Pin configurations.

## Illumination

For testing the illum functionality, POT_LUMINANCE shall be rotated in both directions to check if the light beam is toggling between leds LED_ILLUM_NIGHT and LED_ILLUM_DAY.

## Blink

### Short left blink

Press the BTN_LEFT button and LED_TURN_FRONT_LEFT , LED_TURN_BACK_LEFT shall perform 3 sequences of blink.

### Short right blink

Press the BTN_RIGHT button and LED_TURN_FRONT_RIGHT , LED_TURN_BACK_RIGHT shall perform 3 sequences of blink.

### Hazard

Press the BTN_HAZARD button and LED_TURN_FRONT_LEFT, LED_TURN_BACK_LEFT, LED_TURN_FRONT_RIGHT, LED_TURN_BACK_RIGHT shall perform continuous sequences of blink.

Press BTN_LEFT. No process shall be initiated, all 4 leds still blinking in hazard mode.

Press BTN_RIGHT. No process shall be initiated, all 4 leds still blinking in hazard mode.

Press BTN_HAZARD to stop the hazard test.

### Long left blink

Press the BTN_LEFT button for one second and LED_TURN_FRONT_LEFT , LED_TURN_BACK_LEFT shall perform continuous sequences of blink.

Press BTN_LEFT to stop.

Press BTN_LEFT for one second to reinitiate the process.

Simulate the steering wheel while left turn signal is on. For this, turn JOY_STEER to right side. No effect expected.

Turn JOY_STEER to left side. Blinking shall stop.

### Long right blink

Press the BTN_RIGHT button for one second and LED_TURN_FRONT_RIGHT , LED_TURN_BACK_RIGHT shall perform continuous sequences of blink.

Press BTN_RIGHT to stop.

Press BTN_RIGHT for one second to reinitiate the process.

Simulate the steering wheel while right turn signal is on. For this, turn JOY_STEER to left side. No effect expected.

Turn JOY_STEER to right side. Blinking shall stop.

## Direction

By default, the system is set to parallel direction style. This means that both servomotors, SERVO_TURN_LEFT and SERVO_TURN_RIGHT shall perform the rotation at the same angle. Check this by rotating left and right the JOY_STEER.

## Horn

By default, horn is set to continuous mode. For checking this, press BUZZ_BTN and BUZZ_HORN shall make a continuous sound while the button is pressed.

## Configuration Mode

For accessing this mode, press BTN_LEFT and BTN_RIGHT simultaneously. Once the system entered in this state, check if:

1.LED_TURN_FRONT_LEFT is turned on

2.LED_ILLUM_NIGHT and LED_ILLUM_DAY are turned off

3.SERVO_TURN_LEFT and SERVO_TURN_RIGHT are rotated in opposite angles.

4. DISP7SEG is turned ON and is showing number ‘0’.

### Wheel Geometry

Currently the geometry is set to parallel so rotate the POT_LUMINANCE in order to set the direction to Ackermann Style. The rotation shall be performed until number ‘1’ is showing on DISP7SEG. Attention, if the number ‘1’ is already showed, no action is required for POT_LUMINANCE. Next step would be to save the change by pressing BUZZ_BTN. While this button is pressed, both points from DISP7SEG are turned ON.

### Illum leds speed transition

Press BTN_RIGHT for next configuration which represents the speed of transition from LED_ILLUM_NIGHT to LED_ILLUM_DAY and reverse when POT_LUMINANCE is changing its current value.

Check if LED_TURN_FRONT_RIGHT is turned ON. This means the system is in transition speed configuration.

Rotate POT_LUMINANCE until the value showed on DISP7SEG is equal to ‘10’ and press BUZZ_BTN to save. This value of 10 is just an example meaning that the transition between illuminations leds will be performed in 100 ms.

### Horn configuration

Press BTN_RIGHT for next configuration and check if LED_TURN_BACK_RIGHT and LED_ILLUM_NIGHT are turned ON.

In the current menu, horn can be set to work in 2 possible modes:

- 0 – continuous
- 1 – PWM

By default it is set to continuous , rotate POT_LUMINANCE until number ‘1’ is showed on DISP7SEG and press BUZZ_BTN to save.

This menu has another extra configuration which represents the duty cycle of the PWM signal for horn. It is responsible for controlling the length (periodicity) of the horn sounds. For this, press

BTN_HAZARD and LED_ILLUM_DAY will be turned ON.

Rotate POT_LUMINANCE until value ‘5’ is showed on DISP7SEG and press BUZZ_BTN to save. By this, the periodicity of the PWM signal will be set to 50 milliseconds.

### Blinking period

Press BTN_RIGHT for next configuration and check if LED_TURN_BACK_LEFT and LED_ILLUM_NIGHT are turned ON.

In the current menu, it will be configured the number of blink sequences and the periodicity. Attention, the number of sequences is available only for short blink mode.

Rotate POT_LUMINANCE until value ‘25’ is showed on DISP7SEG and click BUZZ_BTN to save. Periodicity will be set to 250 ms.

For number of sequences, click HAZARD_BTN and LED_ILLUM_DAY will be turned ON.

Rotate POT_LUMINANCE until value ‘5’ is showed on DISP7SEG and click BUZZ_BTN to save. Number of blinks will be set to 5.

Hold BTN_LEFT and BTN_RIGHT simultaneously to exit configuration menu.

## Final check

Now that all settings have been updated, it is required to test them.

1. Check Ackermann Geometry by rotating JOY_STEER. SERVO_TURN_LEFT and SERVO_TURN_RIGHT should have different angle rotation, always the interior angle is greater than the exterior one.
2. Check if horn is set to PWM mode by pressing BUZZ_BTN.
3. Press LEFT_BTN and check if both left side leds are blinking 5 times with a periodicity of 250 ms.
4. Press RIGHT_BTN and check if both right side leds are blinking 5 times with a periodicity of 250 ms.
5. Rotate POT_LUMINANCE and check if the transition time from one luminance led to another is smaller than before the configuration changed.

# 4 Information about this Document

## 1.1 Copyright

All rights, including translation rights, are reserved. Under no circumstances shall any fragment of this document be reproduced without written authorization from NTT DATA Romania S.A, including copying, photographing or replicating through other methods.

Copyright (c) NTT DATA Romania S.A.

## 1.2 Version Index

Vers. | Date | Author | Chapter | Modification description
1.0 | 12.06.2021 | Alexandru-Sebastian Anghel | All | Created.
1.1 | 12.04.2023 | Alexandru-Sebastian Anghel | 3.5.2 3.5.3 3.5.4 | Modified BTN_LEFT to BTN_RIGHT when switching from one submenu to another while system is configuration menu

Table 3 - Version Index.

Copyright © NTT DATA Romania S.A. Page 11 of 11

Information Type: Working Standard Information Owner: Alexandru-Sebastian Anghel Company: NTT DATA Romania

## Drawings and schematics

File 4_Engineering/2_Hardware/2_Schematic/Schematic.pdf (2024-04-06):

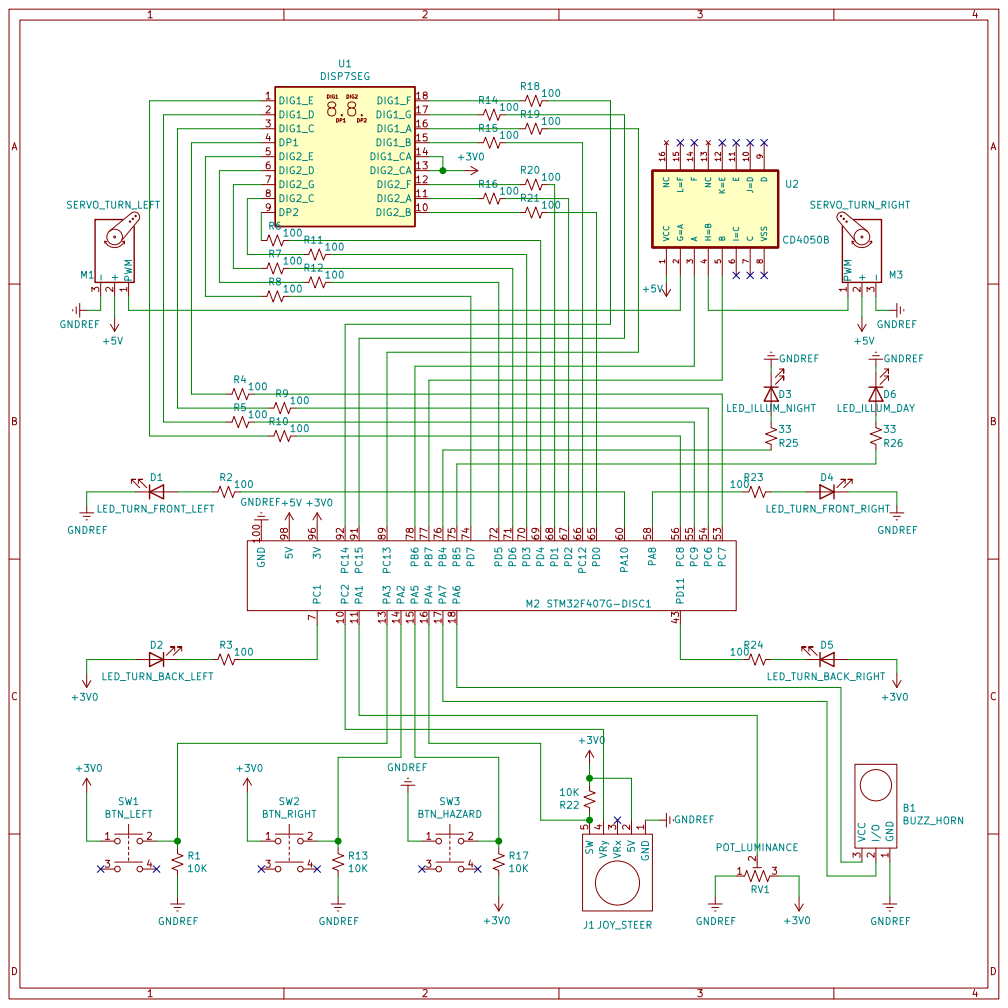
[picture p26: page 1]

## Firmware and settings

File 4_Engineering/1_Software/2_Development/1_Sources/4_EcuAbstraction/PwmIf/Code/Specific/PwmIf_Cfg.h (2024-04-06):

/*-------------------------------------------------------------------------------------------------------------------*/
/**
 *    \file       PwmIf_Cfg.h
 *    \author     Nicolae-Bogdan Bacrau
 *    \brief      Redefines all the PWM channels, adding information about the used peripherals.
 */
/*-------------------------------------------------------------------------------------------------------------------*/

#ifndef PWMIF_CFG_H
#define PWMIF_CFG_H

/*-------------------------------------------------------------------------------------------------------------------*/
/*                                                     Inclusions                                                    */
/*-------------------------------------------------------------------------------------------------------------------*/

/*-------------------------------------------------------------------------------------------------------------------*/
/*                                            Definition Of Global Macros                                            */
/*-------------------------------------------------------------------------------------------------------------------*/

/** \brief     Defines the ID of the night illumination LED PWM channel as the uC internal PWM B4 channel. */
#define PWMIF_LED_ILLUM_NIGHT             ((PwmIf_ChannelType) PWM_B_4)

/** \brief     Defines the ID of the day illumination LED PWM channel as the uC internal PWM B5 channel. */
#define PWMIF_LED_ILLUM_DAY               ((PwmIf_ChannelType) PWM_B_5)

/** \brief     Defines the ID of the left servomotor PWM channel as the uC internal PWM B6 channel. */
#define PWMIF_SERVO_TURN_LEFT             ((PwmIf_ChannelType) PWM_B_6)

/** \brief     Defines the ID of the right servomotor PWM channel as the uC internal PWM B7 channel. */
#define PWMIF_SERVO_TURN_RIGHT            ((PwmIf_ChannelType) PWM_B_7)

/*-------------------------------------------------------------------------------------------------------------------*/
/*                                          Definition Of Global Data Types                                          */
/*-------------------------------------------------------------------------------------------------------------------*/

/*-------------------------------------------------------------------------------------------------------------------*/
/*                                          Definition Of Global Data Types                                          */
/*-------------------------------------------------------------------------------------------------------------------*/

/*-------------------------------------------------------------------------------------------------------------------*/
/*                                             Export Of Global Constants                                            */
/*-------------------------------------------------------------------------------------------------------------------*/

/*-------------------------------------------------------------------------------------------------------------------*/
/*                                             Export Of Global Variables                                            */
/*-------------------------------------------------------------------------------------------------------------------*/

/*-------------------------------------------------------------------------------------------------------------------*/
/*                                             Export Of Global Functions                                            */
/*-------------------------------------------------------------------------------------------------------------------*/

/*-------------------------------------------------------------------------------------------------------------------*/
#endif /* PWMIF_CHANNELS_H */

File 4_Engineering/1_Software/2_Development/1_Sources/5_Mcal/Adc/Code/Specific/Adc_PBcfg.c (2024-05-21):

/*-------------------------------------------------------------------------------------------------------------------*/
/**
 *    \file       Adc_PBcfg.c
 *    \author     Andrei-Cristian Onea
 *    \brief      Sets up the AUTOSAR ADC driver configuration using the Init data types for masked 32 bits
 *                registers.
 */
/*-------------------------------------------------------------------------------------------------------------------*/

/*-------------------------------------------------------------------------------------------------------------------*/
/*                                                     Inclusions                                                    */
/*-------------------------------------------------------------------------------------------------------------------*/

#include "Adc.h"
#include "Adc_Cfg.h"
#include "stm32f407xx.h"

/*-------------------------------------------------------------------------------------------------------------------*/
/*                                             Definition Of Local Macros                                            */
/*-------------------------------------------------------------------------------------------------------------------*/

/** \brief     Defines the total number of registers to be loaded in the initialization function. */
#define ADC_NUMBER_OF_INIT_REGISTERS      (8U)

/*-------------------------------------------------------------------------------------------------------------------*/
/*                                           Definition Of Local Data Types                                          */
/*-------------------------------------------------------------------------------------------------------------------*/

/*-------------------------------------------------------------------------------------------------------------------*/
/*                                           Declaration Of Local Variables                                          */
/*-------------------------------------------------------------------------------------------------------------------*/

/*-------------------------------------------------------------------------------------------------------------------*/
/*                                          Declaration Of Global Variables                                          */
/*-------------------------------------------------------------------------------------------------------------------*/

/*-------------------------------------------------------------------------------------------------------------------*/
/*                                           Declaration Of Local Constants                                          */
/*-------------------------------------------------------------------------------------------------------------------*/

/** \brief     Stores the configuration of all the registers to be set in the ADC initialization function. */
static const Init_Masked32BitsSingleType Adc_kat_Registers[ADC_NUMBER_OF_INIT_REGISTERS] =
{
    /* Set the resolution of the conversion to 12 bits. */
    {
        (volatile uint32*) (&ADC1->CR1),

        (uint32) ~(ADC_CR1_RES),

        (uint32) (0UL)
    },

    /* Set the alignment of the conversion to right. */
    /* Enable ADC1 hardware unit (ADON). */
    {
        (volatile uint32*) (&ADC1->CR2),

        (uint32) ~(
        ADC_CR2_ALIGN |
        ADC_CR2_ADON),

        (uint32) (0UL | 
        ADC_CR2_ADON)
    },

    /* Set the channel sequence length to 1 conversion. */
    {
        (volatile uint32*) (&ADC1->SQR1),

        (uint32) ~(ADC_SQR1_L),

        (uint32) (0UL)
    },

    /* Set the channel 0 sampling time to 84 cycles. */
    {
        (volatile uint32*) (&ADC1->SMPR2),

        (uint32) ~(ADC_SMPR2_SMP0),

        (uint32) (ADC_SMPR2_SMP0_2)
    },

    /* Set the resolution of the conversion to 12 bits. */
    {
        (volatile uint32*) (&ADC3->CR1),

        (uint32) ~(ADC_CR1_RES),

        (uint32) (0UL)
    },

    /* Set the alignment of the conversion to right. */
    /* Enable ADC3 hardware unit (ADON). */
    {
        (volatile uint32*) (&ADC3->CR2),

        (uint32) ~(
        ADC_CR2_ALIGN |
        ADC_CR2_ADON),

        (uint32) (0UL | 
        ADC_CR2_ADON)
    },

    /* Set the channel sequence length to 1 conversion. */
    {
        (volatile uint32*) (&ADC3->SQR1),

        (uint32) ~(ADC_SQR1_L),

        (uint32) (0UL)
    },

    /* Set the channel 0 sampling time to 84 cycles. */
    {
        (volatile uint32*) (&ADC3->SMPR2),

        (uint32) ~(ADC_SMPR2_SMP0),

        (uint32) (ADC_SMPR2_SMP0_2)
    }
};

/** \brief     Stores the configuration of all the ADC channel groups. */
static const Adc_ChannelConfigType GroupConfigADC[ADC_NUMBER_OF_GROUPS] =
{
    {
        ADC1,
        (1U)
    },
    {
        ADC3,
        (12U)
    }
};

/*-------------------------------------------------------------------------------------------------------------------*/
/*                                          Declaration Of Global Constants                                          */
/*-------------------------------------------------------------------------------------------------------------------*/

/** \brief     References the configuration of all the registers to be set in the ADC initialization function and the
 *             number of registers to be initialized. */
const Init_Masked32BitsConfigType Adc_gkt_Init =
{
    Adc_kat_Registers,
    ADC_NUMBER_OF_INIT_REGISTERS
};

/** \brief     References the configuration of all the registers to be set in the ADC initialization function and the
 *             number of registers to be initialized. */
Adc_gkt_Config =
{
    &Adc_gkt_Init,
    GroupConfigADC
};

/*-------------------------------------------------------------------------------------------------------------------*/
/*                                           Declaration Of Local Functions                                          */
/*-------------------------------------------------------------------------------------------------------------------*/

/*-------------------------------------------------------------------------------------------------------------------*/
/*                                         Implementation Of Local Functions                                         */
/*-------------------------------------------------------------------------------------------------------------------*/

/*-------------------------------------------------------------------------------------------------------------------*/
/*                                         Implementation Of Global Functions                                        */
/*-------------------------------------------------------------------------------------------------------------------*/

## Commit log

2024-04-29 ADC partial
2024-05-21 ADC finished
2024-05-21 ADC feedback 1
